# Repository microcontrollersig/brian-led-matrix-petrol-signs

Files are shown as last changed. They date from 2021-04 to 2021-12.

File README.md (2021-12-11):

# Big LED Matrix from Petrol Pump Signage

#### Info

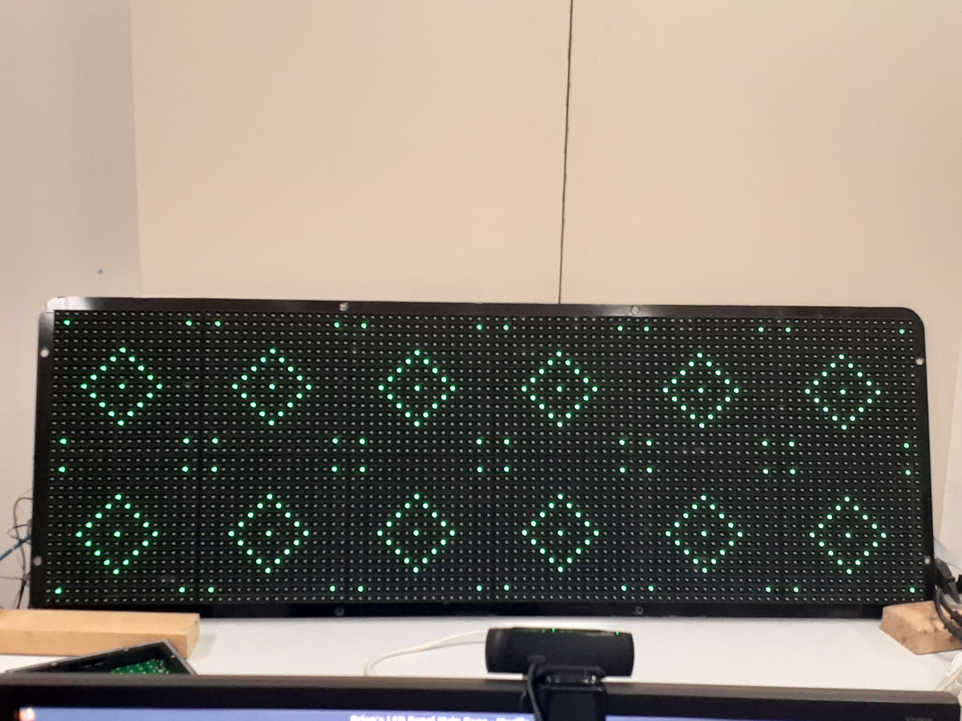
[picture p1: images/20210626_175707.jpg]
LED Panel Demo


Not the usual HUB08/HUB12/HUB40/HUB75 style setup. Inner workings [here](https://github.com/microcontrollersig/brian-led-matrix-petrol-signs/blob/main/REVERSEENGINEER.md)

They usually come in 6 panels wide, 2 panels height (effectively becomes a 96x32 single-color LED matrix)

# PCB Controller for LED matrix

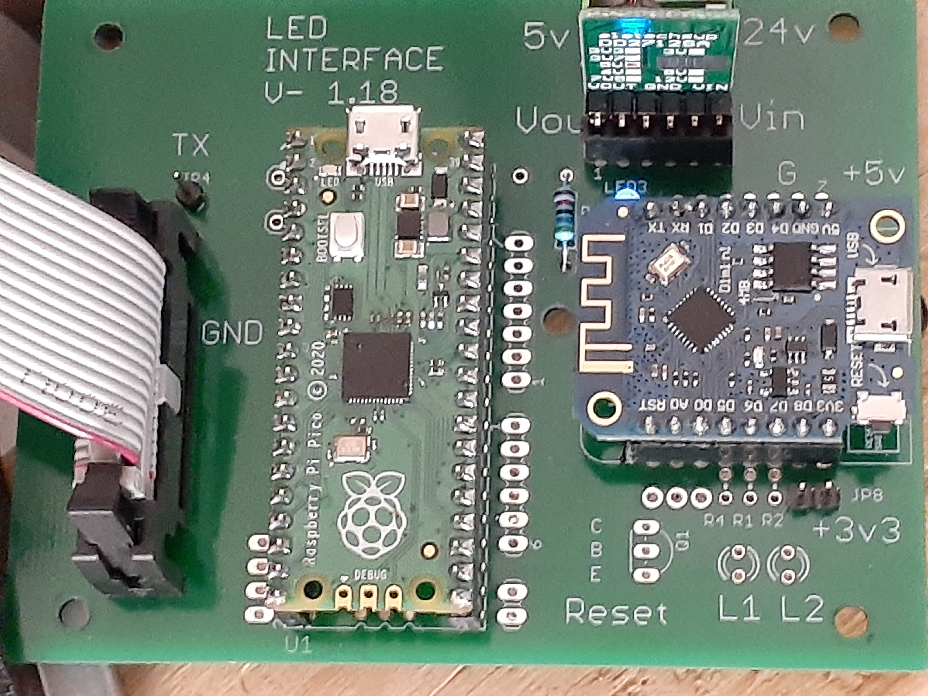
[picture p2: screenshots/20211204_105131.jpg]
LED matrix controller


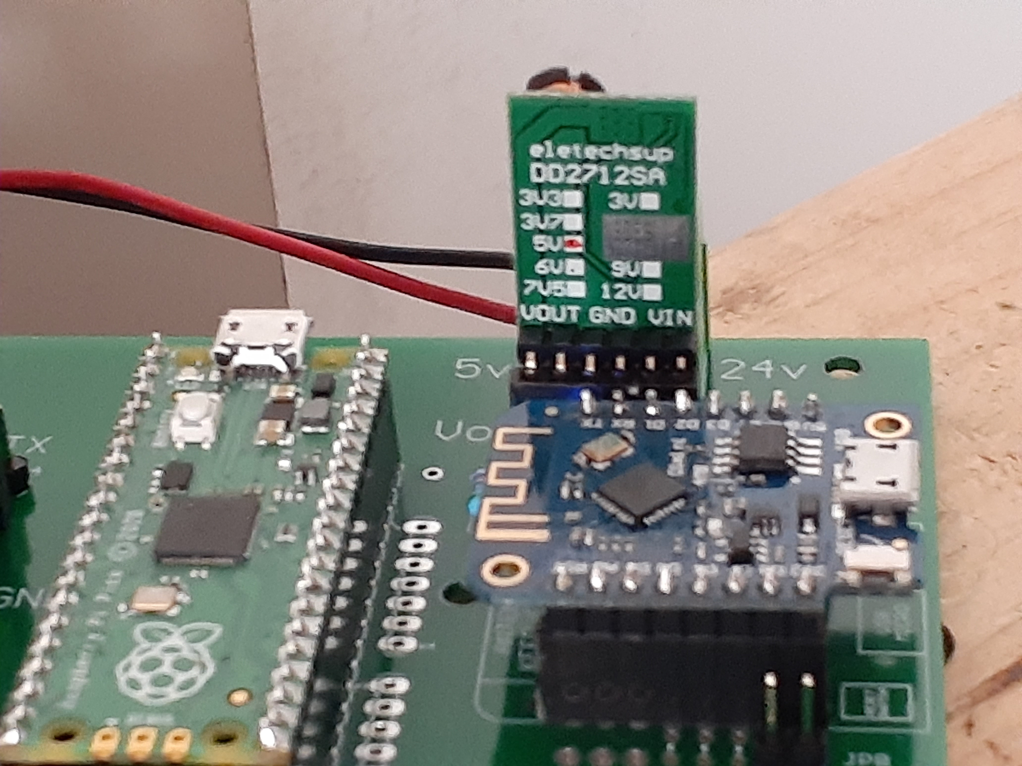
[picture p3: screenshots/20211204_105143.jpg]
PCB controller


#### Bill of Materials

| Qty | | Code | Where to Buy | Required |
| --- | --- | --- | --- | --- |
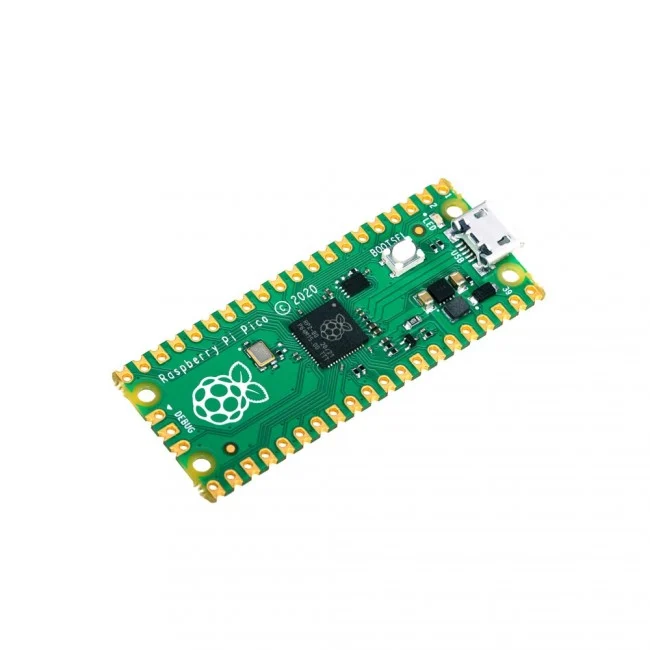
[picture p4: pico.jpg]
Pico
| 1 |  | [Raspberry Pico](https://www.raspberrypi.org/documentation/rp2040/getting-started/) | [Pi Australia](https://raspberry.piaustralia.com.au/products/raspberry-pi-pico?variant=32587824070705)<br/>[Altronics](https://www.altronics.com.au/p/z6421-raspberry-pi-pico-microcontroller-board/)<br/>[Element 14](https://au.element14.com/raspberry-pi/raspberry-pi-pico/raspberry-pi-32bit-arm-cortex/dp/3643332)<br/>[Core Electronics](https://core-electronics.com.au/raspberry-pi-pico.html) | Y |
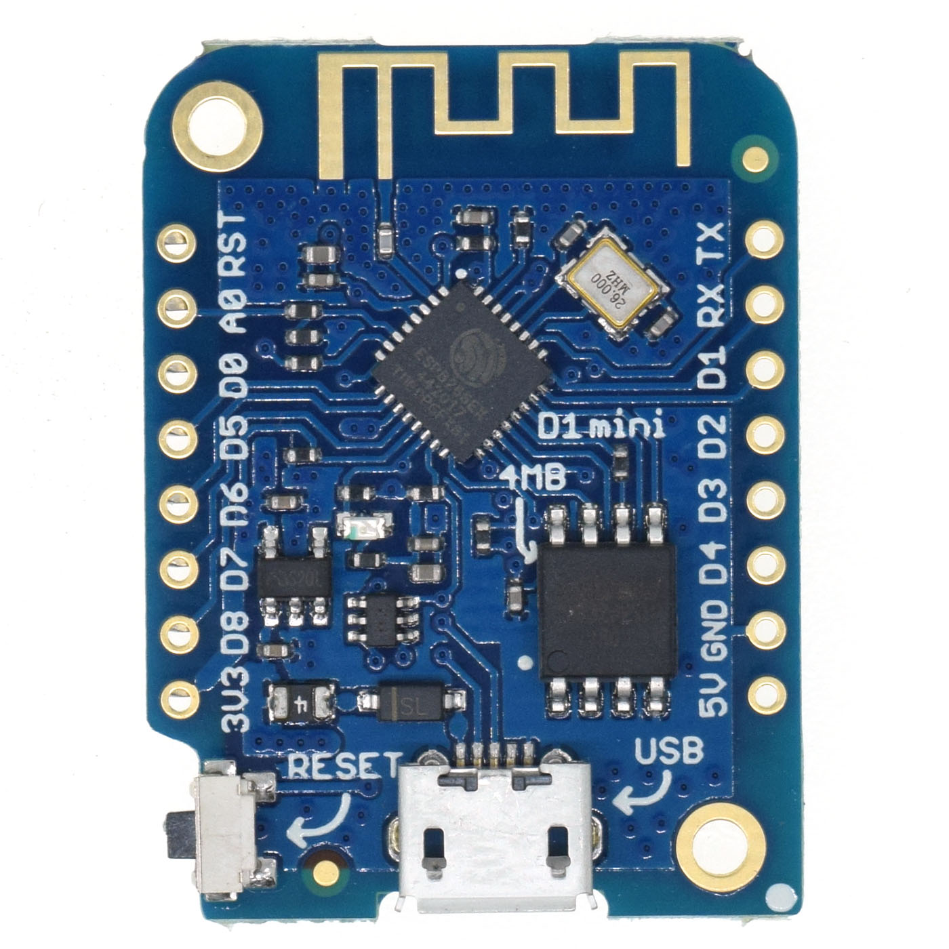
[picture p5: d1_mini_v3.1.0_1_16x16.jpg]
D1 mini
| 1 |  | [ESP8266 Wemos D1 mini](https://www.wemos.cc/en/latest/d1/d1_mini.html) | [Aliexpress - color: d1 mini](https://www.aliexpress.com/item/32651747570.html) | Y |
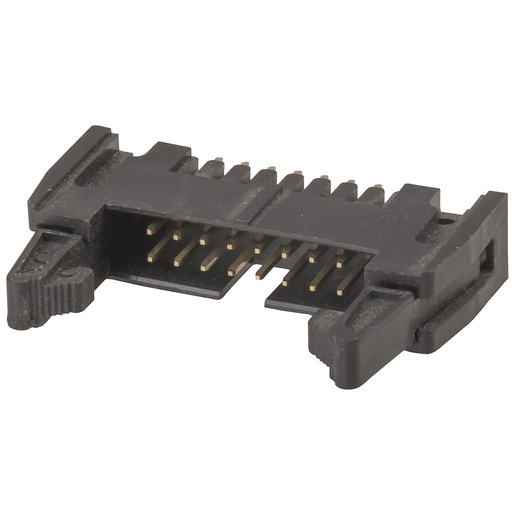
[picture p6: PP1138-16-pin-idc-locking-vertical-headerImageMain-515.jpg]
16 Pin IDC
| 1 |  | [16 Pin IDC Locking Vertical Header](https://www.jaycar.com.au/16-pin-idc-locking-vertical-header/p/PP1138) | 16-pin ribbon header | Y |
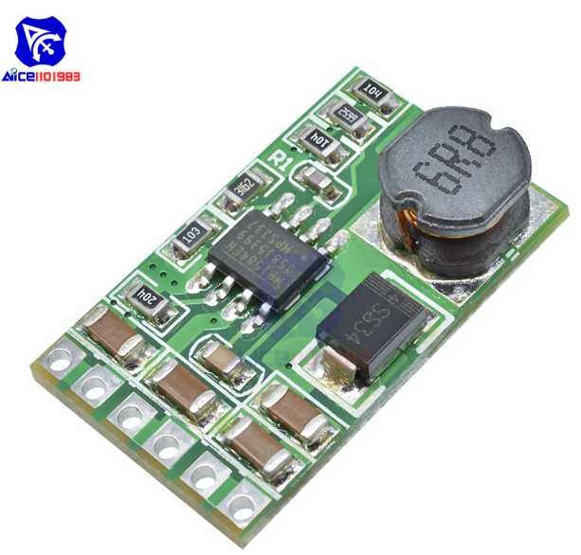
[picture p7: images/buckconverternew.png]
buck converter
| 1 |  | [3.5A buck converter - color: 5V](https://www.aliexpress.com/item/33036075561.html) | Buck converter | Y |
| 1 | Terminal block | [Terminal block](https://www.altronics.com.au/p/p2041a-dinkle-3-way-5.08mm-pcb-mount-terminal-block/) | External power source | Y |
| 1 | Disk Drive Power Connector Socket | [Disk Drive Power Connector Socket](https://www.jaycar.com.au/disk-drive-power-connector-socket/p/PS0742) | Power connector from LEDs to terminal block | N |
| 1 | Female header | [Female header](https://www.jaycar.com.au/40-pin-female-header-strip/p/HM3230) | Female header for Pico | Y |
| 1 | Right-angle connector | [Right-angle connector ](https://www.rockby.com.au/CatresultsSql_12.cfm?select=33&subcode=142&stock_no=27464) | Need for connecting buck converter | Y |
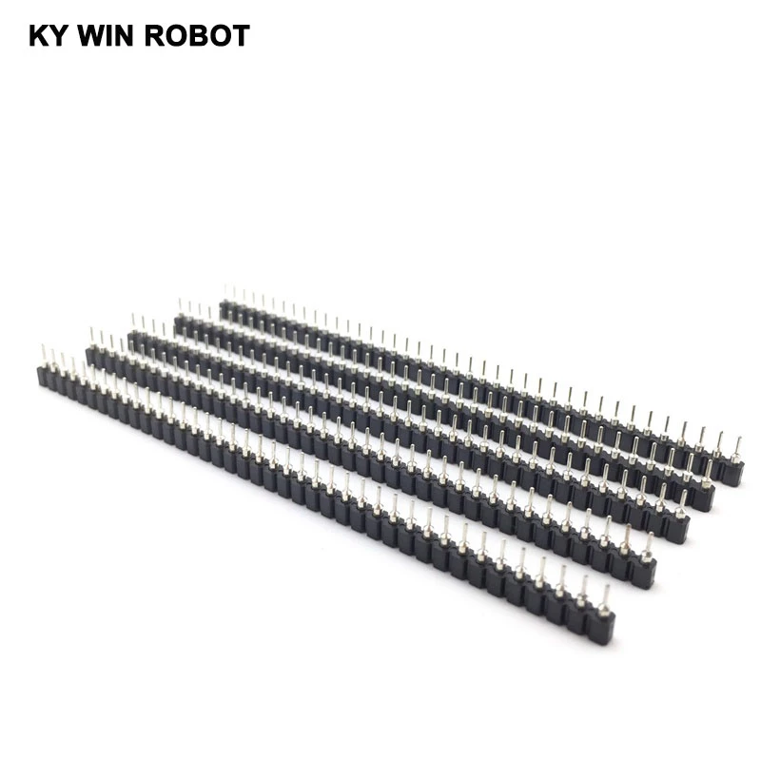
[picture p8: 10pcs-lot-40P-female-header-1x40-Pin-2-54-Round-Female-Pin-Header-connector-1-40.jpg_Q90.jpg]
Female Header
| 1 |  | [Round Female Pin Header connector - snapable](https://www.aliexpress.com/item/32848204130.html) | Aliexpress | N |
| 1 | 2N2222A | [2N2222A NPN transistor](https://www.jaycar.com.au/2n2222a-npn-transistor/p/ZT2298) | Pico software-controlled reset switch | N |

#### EAGLE Schematic for PCB Board

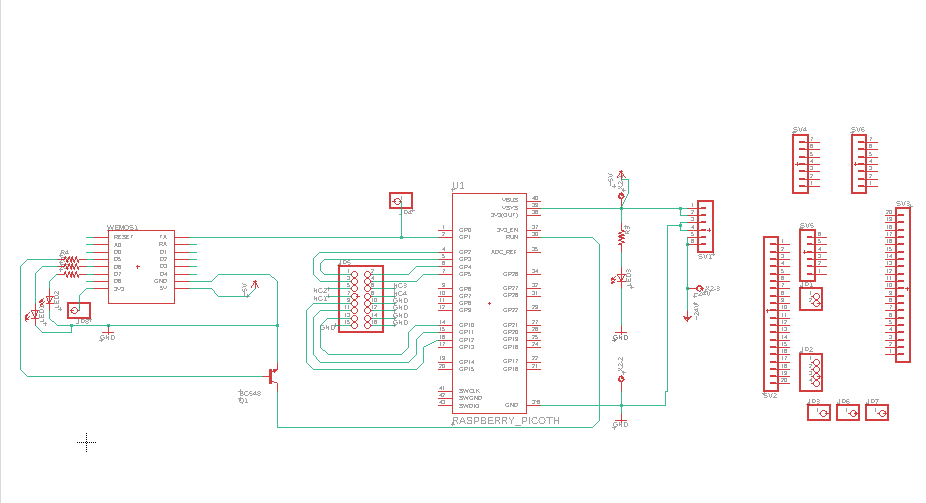
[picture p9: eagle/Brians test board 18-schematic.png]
schematic


#### EAGLE Board file for PCB Board

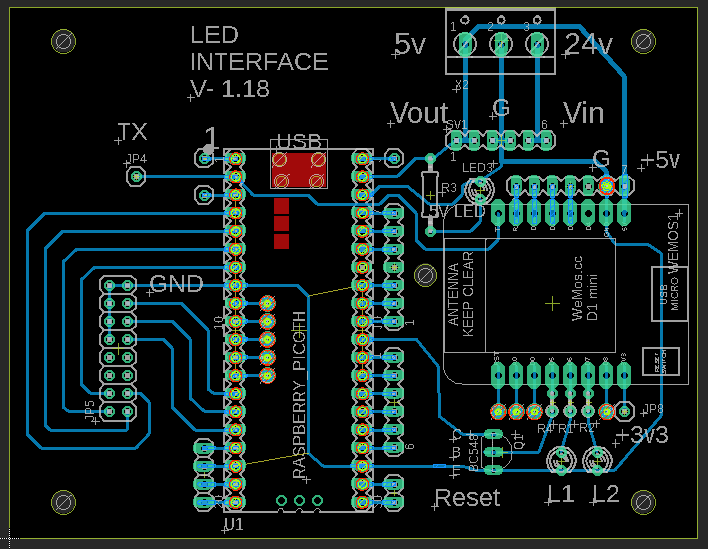
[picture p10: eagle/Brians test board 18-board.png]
board


### PCB Top Layer

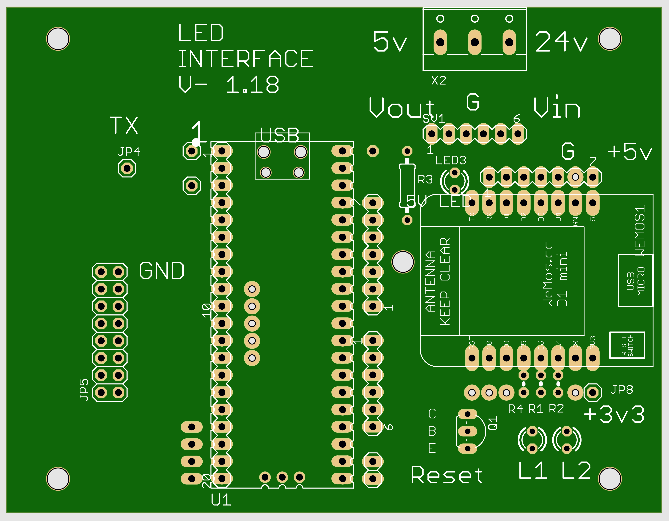
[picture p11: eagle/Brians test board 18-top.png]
PCB Top Layer


#### PCB Bottom Layer

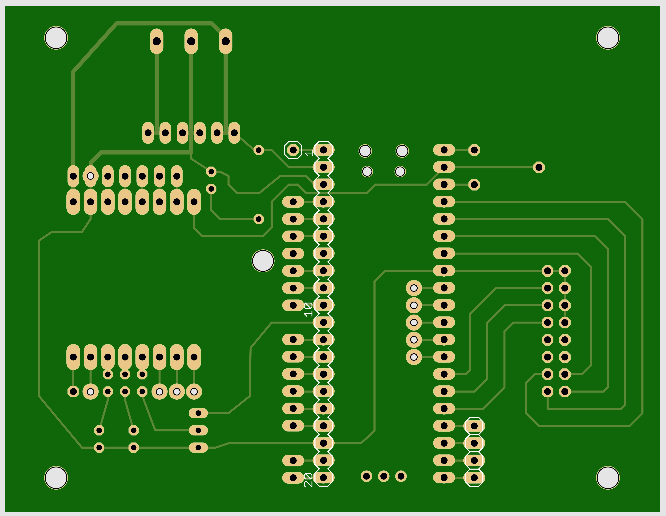
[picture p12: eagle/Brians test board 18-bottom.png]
PCB Bottom Layer


#### Raspberry Pi Pico

pinout

#### ESP8266 wemos d1 mini

pinout

# Software

Steps needed to complete software setup:

- Firmware needs to be uploaded to Pico, firmware also need to be uploaded to esp8266 D1 mini.
- wifi configuration of D1 mini.

In order to complete these steps, must first do the following steps on your computer:

- Download zip file containing firmware files and CH340 Windows driver for D1 mini from [here](https://github.com/microcontrollersig/brian-led-matrix-petrol-signs/releases/latest/download/brian-petrol-signs-easy-firmware-upload.zip) . Unzip the file to a known location on your computer.
- Download a ESP8266 flash utility. There are a number available, my preferred one is ESPHome-Flasher, which can be
  downloaded from [here](https://github.com/esphome/esphome-flasher/releases) .

## Uploading firmware to Raspberry Pico

[Click here for details](https://github.com/microcontrollersig/brian-led-matrix-petrol-signs/tree/main/code/pico).

## Uploading firmware to D1 mini and configuring wifi

[Click here for details](https://github.com/microcontrollersig/brian-led-matrix-petrol-signs/tree/main/code/d1mini)

# Roles of Microprocessors

## Pico

- update LED matrix
- receive commands from the D1 mini via serial(RX).

## ESP8266 D1mini

- Present user with web interface for controlling LED matrix.
- Send commands for the Pico to execute on the LED matrix via Serial(TX).

# References

- [How LED matrix was reverse engineered](https://github.com/microcontrollersig/brian-led-matrix-petrol-signs/blob/main/REVERSEENGINEER.md)

- [Eagle files](https://github.com/microcontrollersig/brian-led-matrix-petrol-signs/tree/main/eagle)

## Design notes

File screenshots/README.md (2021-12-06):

     # Screenshots
 
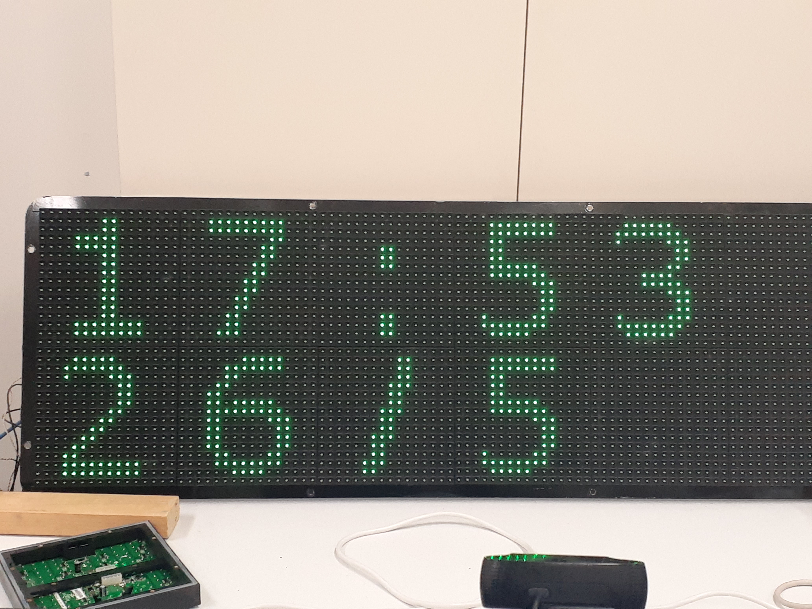
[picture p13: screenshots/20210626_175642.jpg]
   

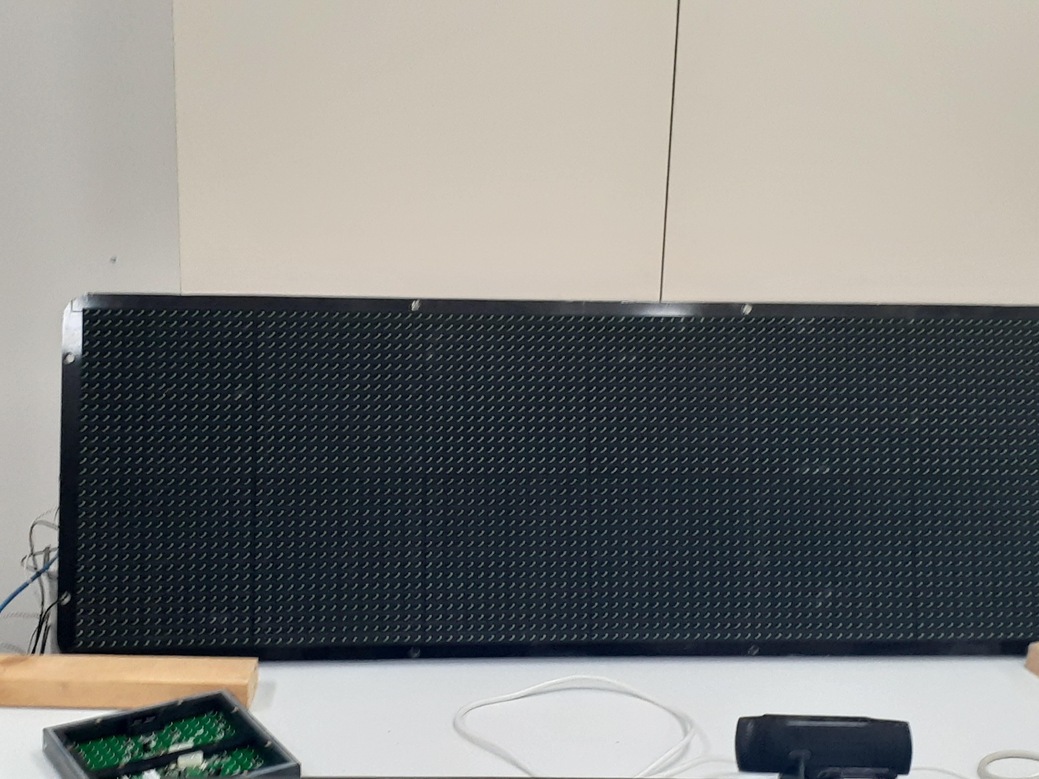
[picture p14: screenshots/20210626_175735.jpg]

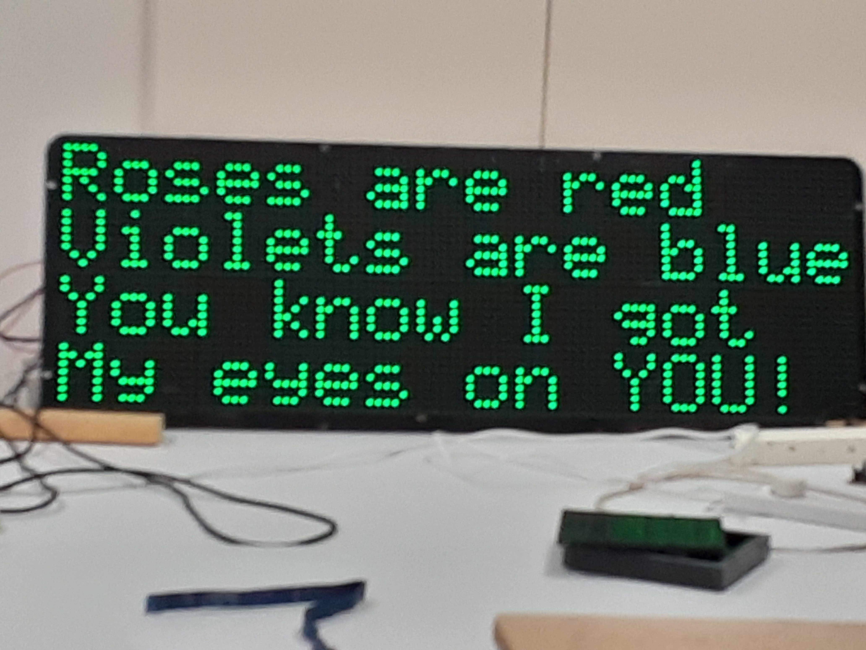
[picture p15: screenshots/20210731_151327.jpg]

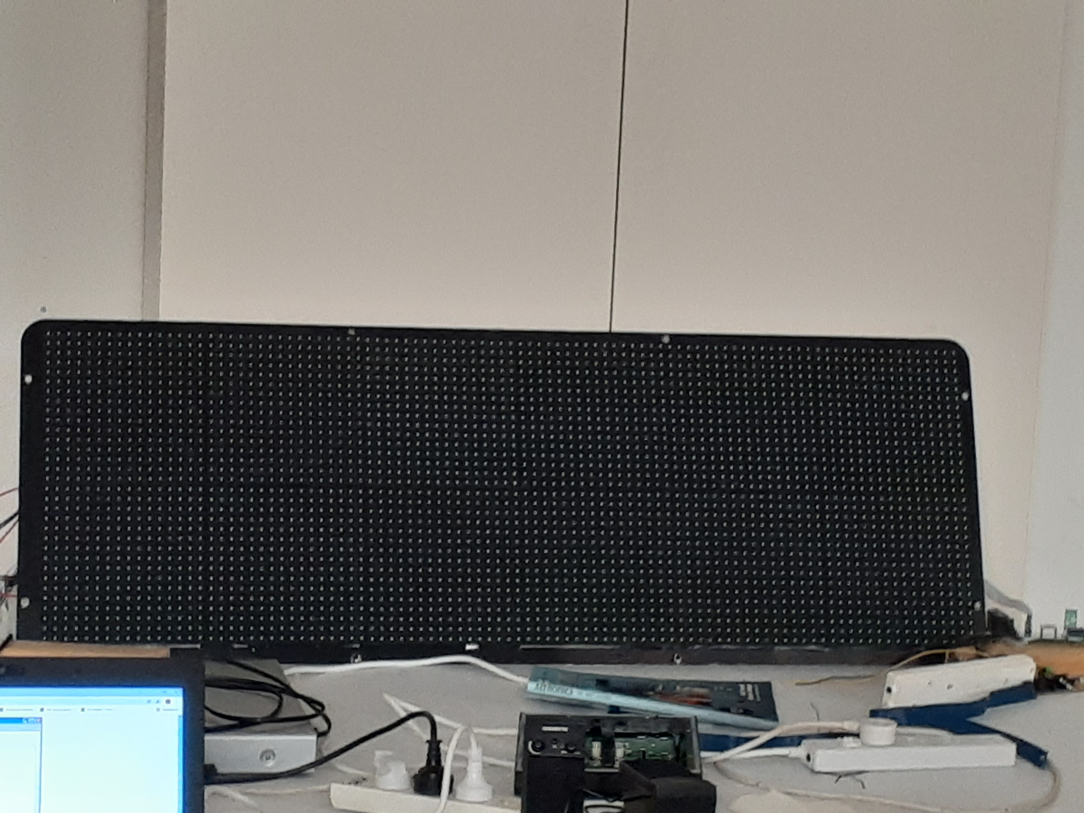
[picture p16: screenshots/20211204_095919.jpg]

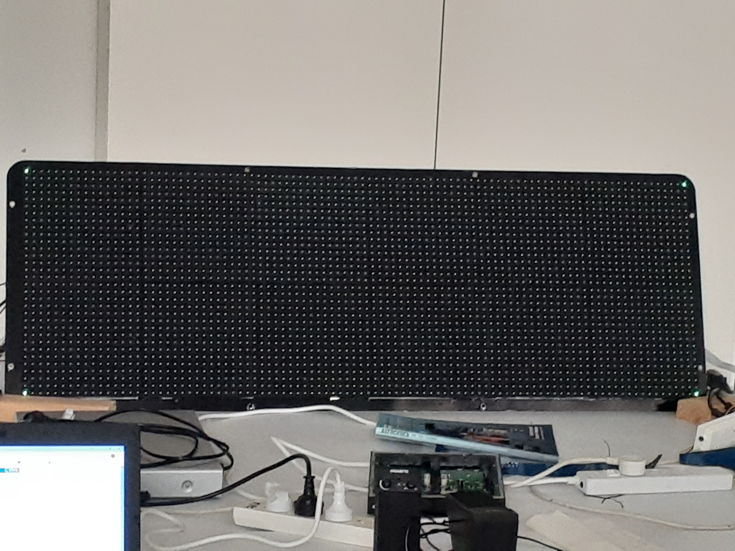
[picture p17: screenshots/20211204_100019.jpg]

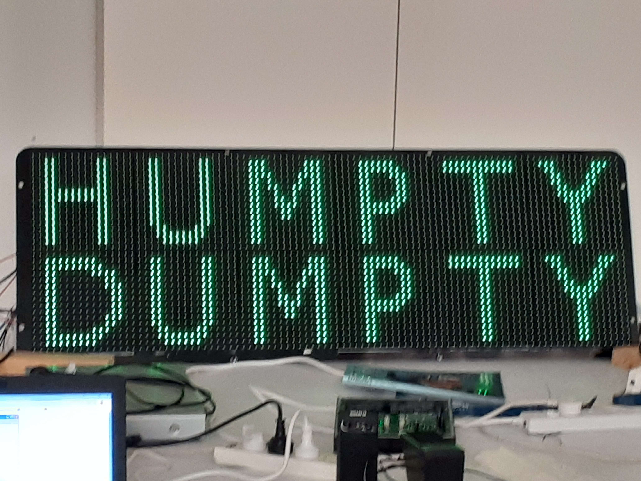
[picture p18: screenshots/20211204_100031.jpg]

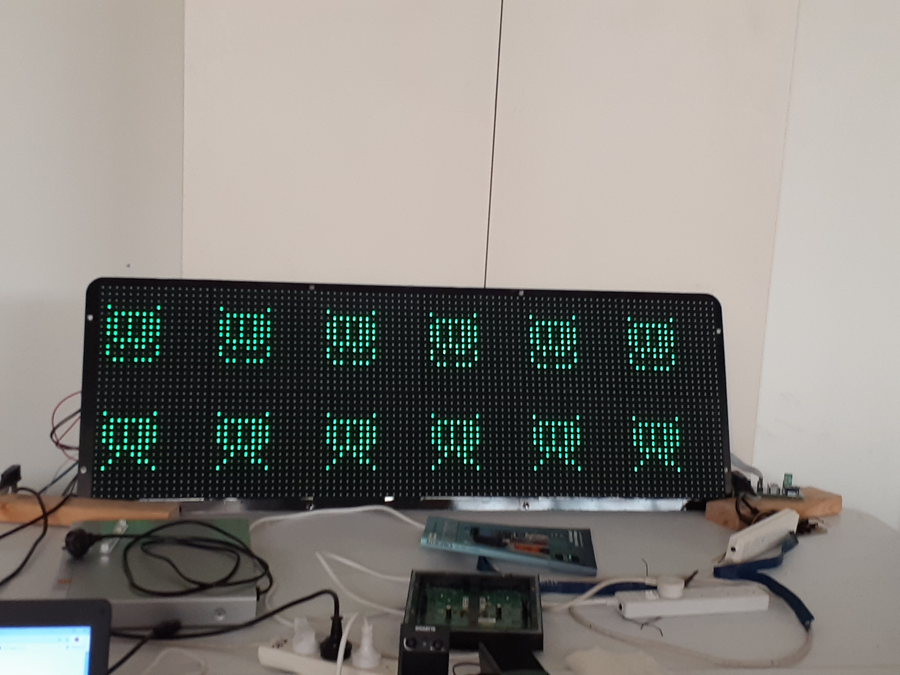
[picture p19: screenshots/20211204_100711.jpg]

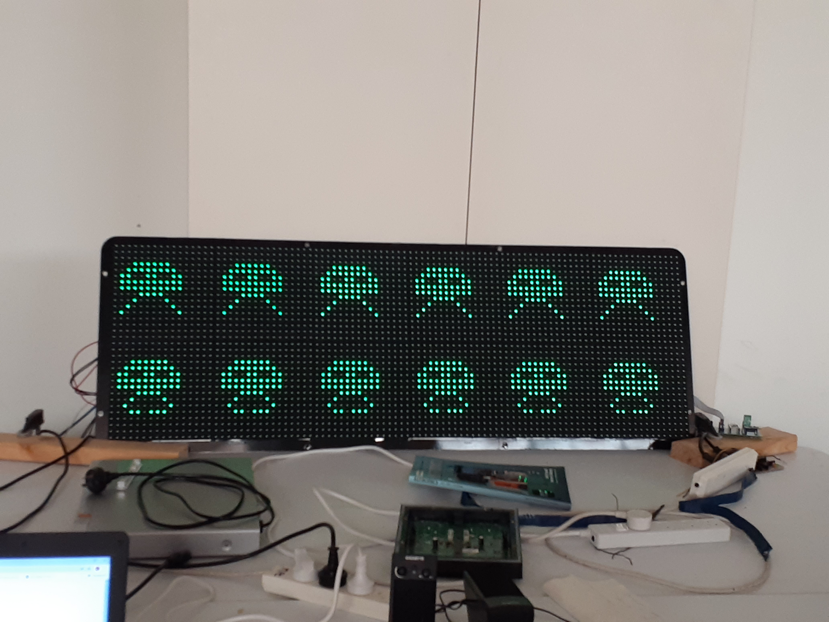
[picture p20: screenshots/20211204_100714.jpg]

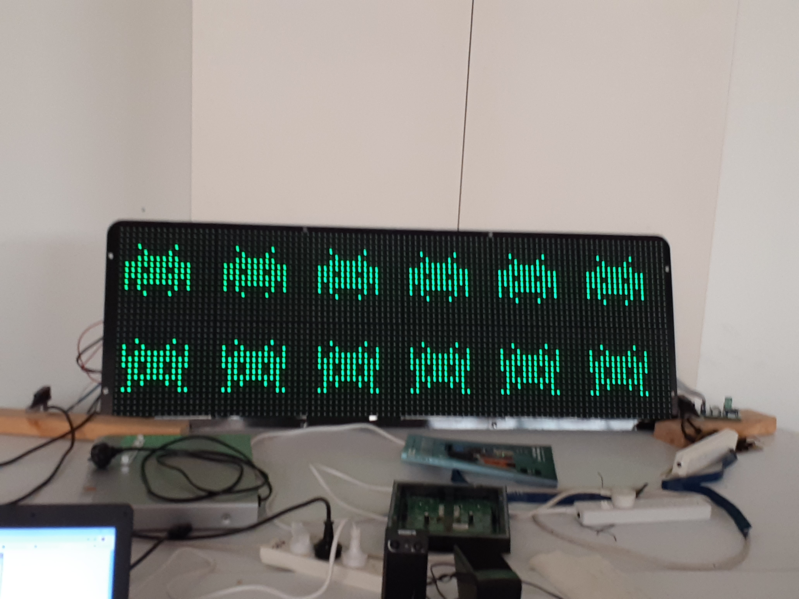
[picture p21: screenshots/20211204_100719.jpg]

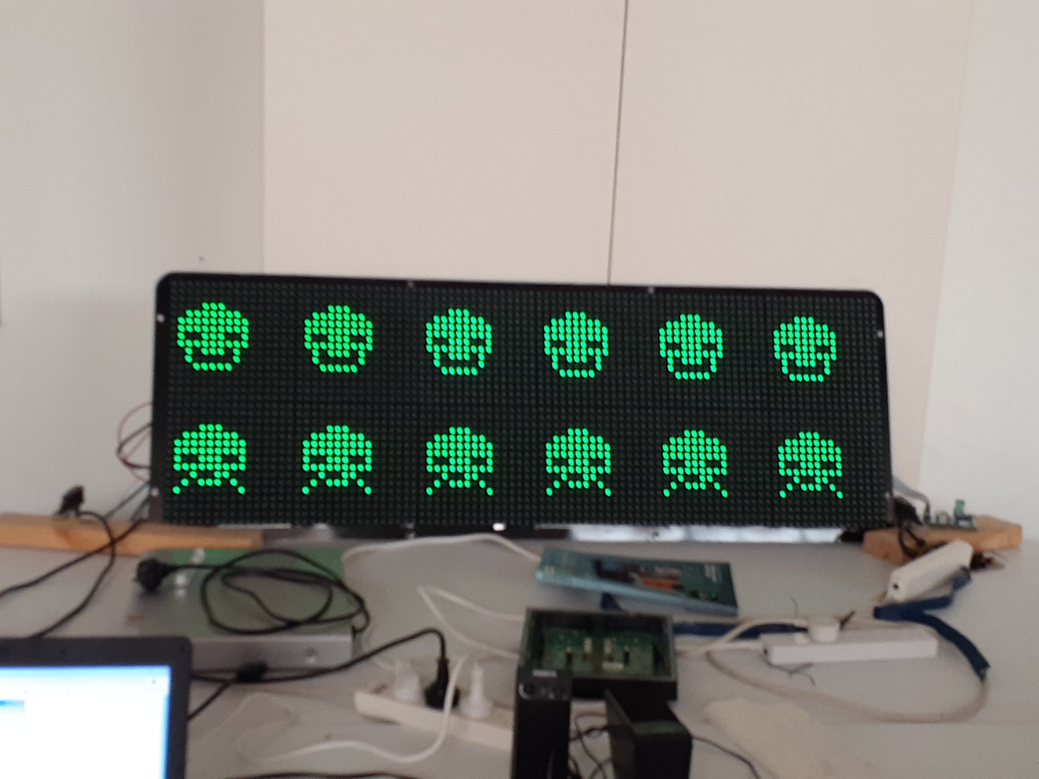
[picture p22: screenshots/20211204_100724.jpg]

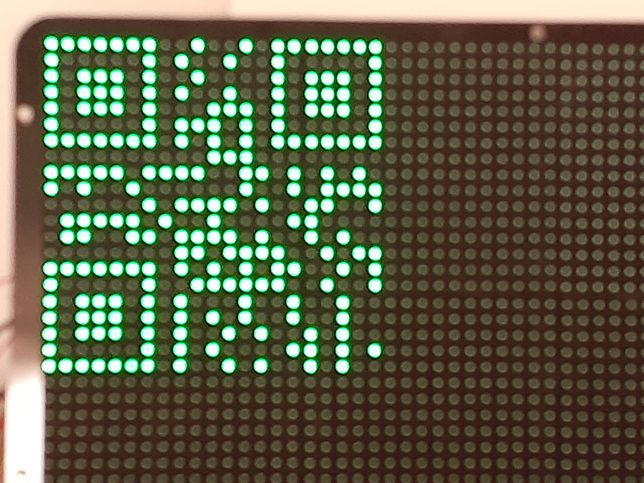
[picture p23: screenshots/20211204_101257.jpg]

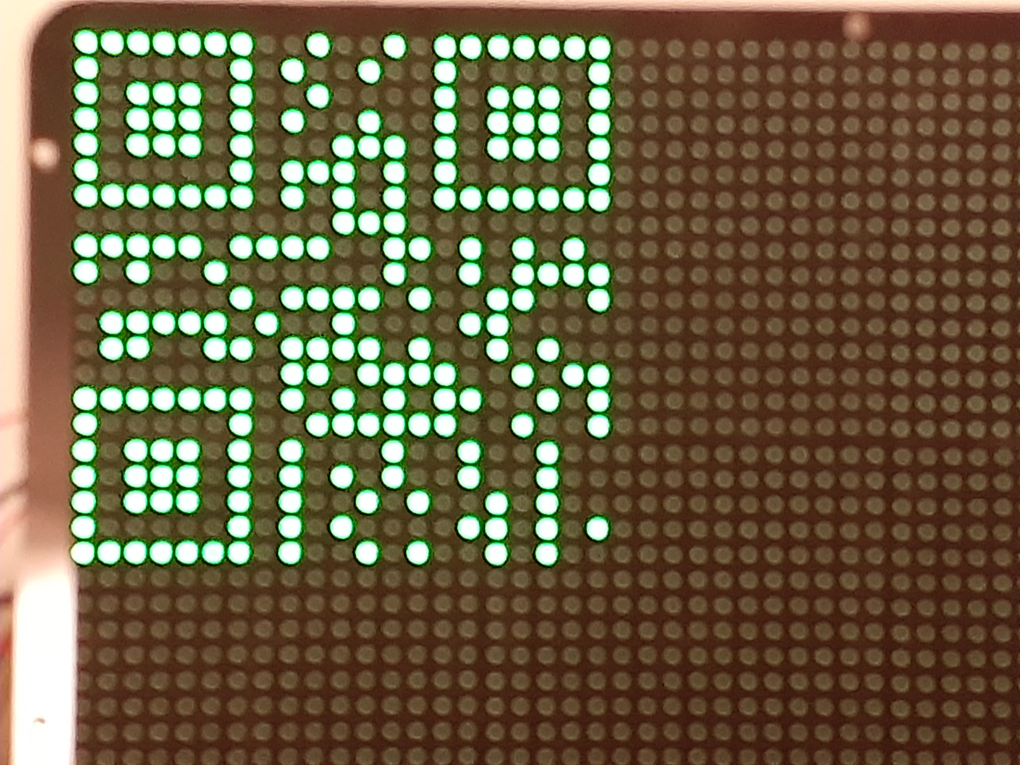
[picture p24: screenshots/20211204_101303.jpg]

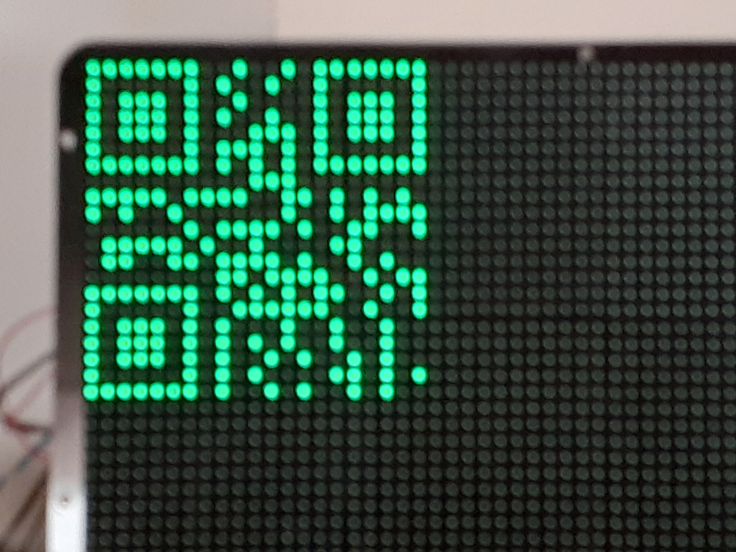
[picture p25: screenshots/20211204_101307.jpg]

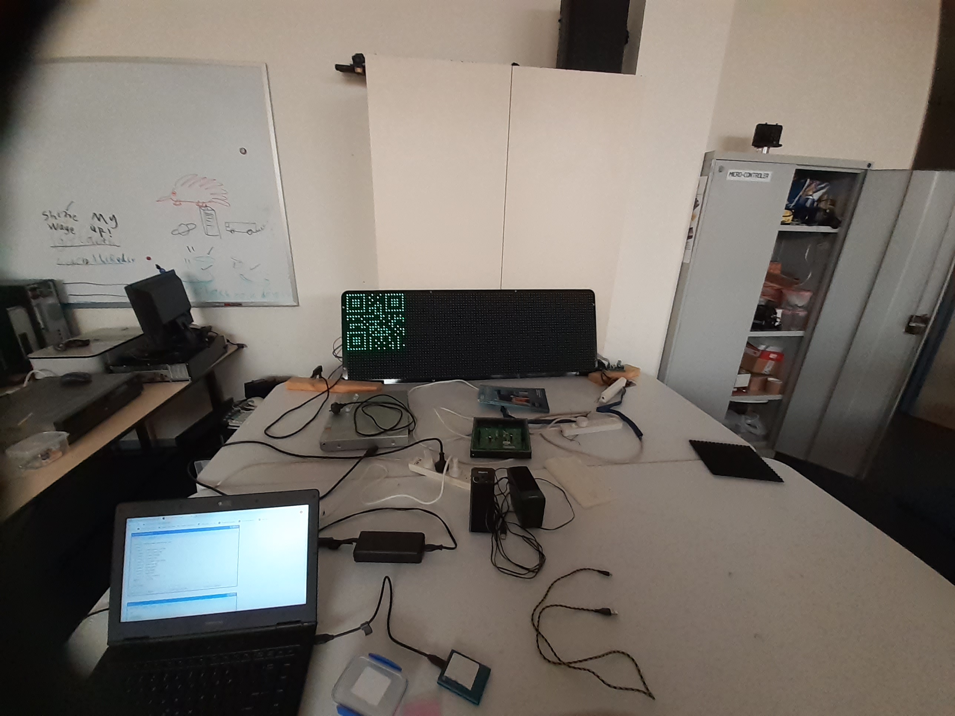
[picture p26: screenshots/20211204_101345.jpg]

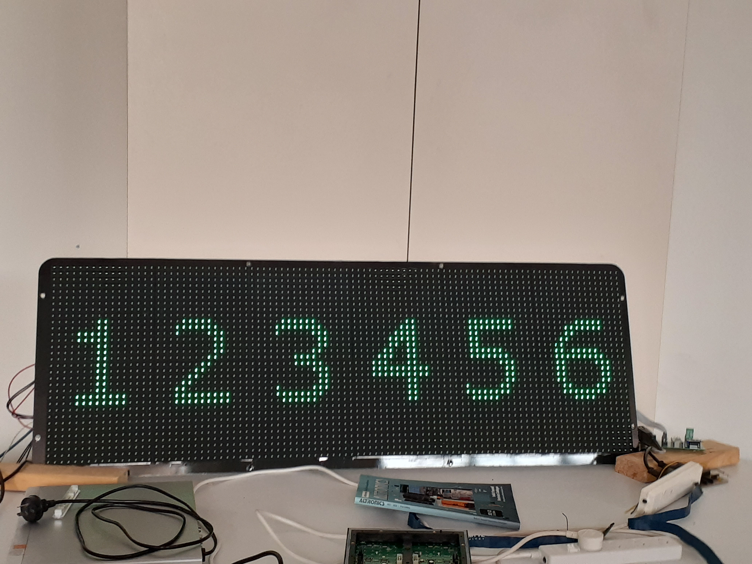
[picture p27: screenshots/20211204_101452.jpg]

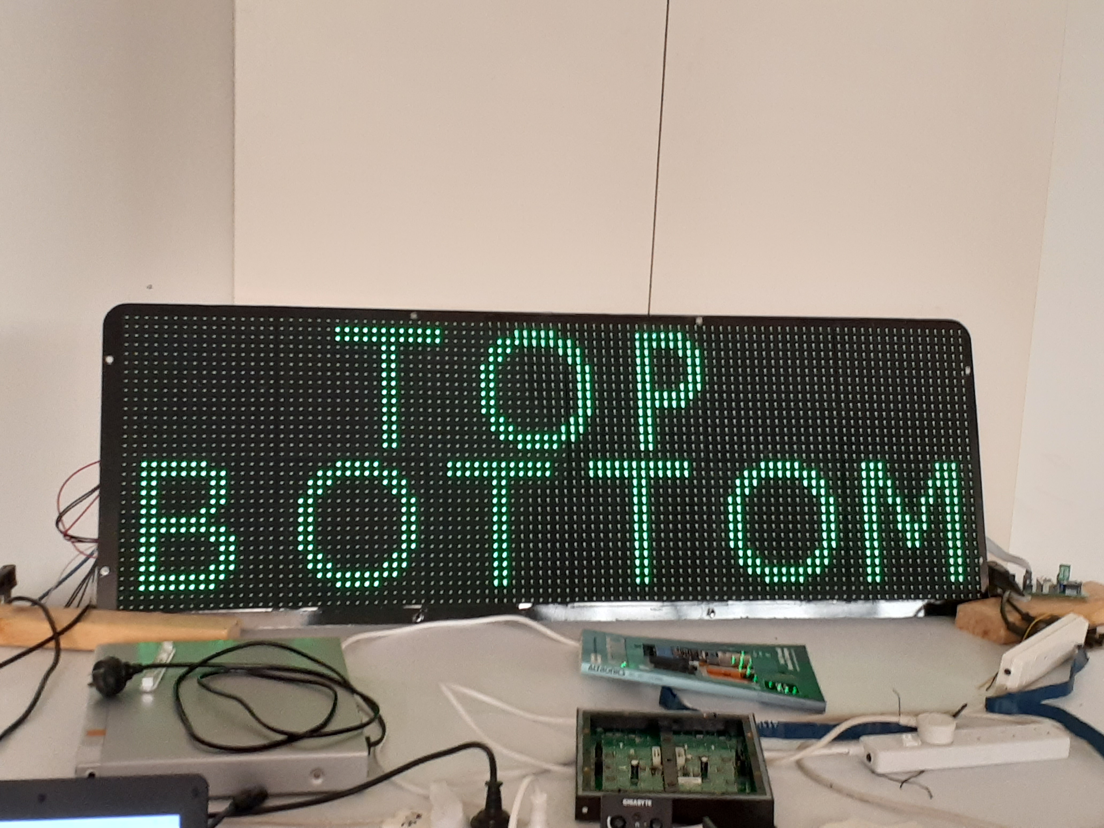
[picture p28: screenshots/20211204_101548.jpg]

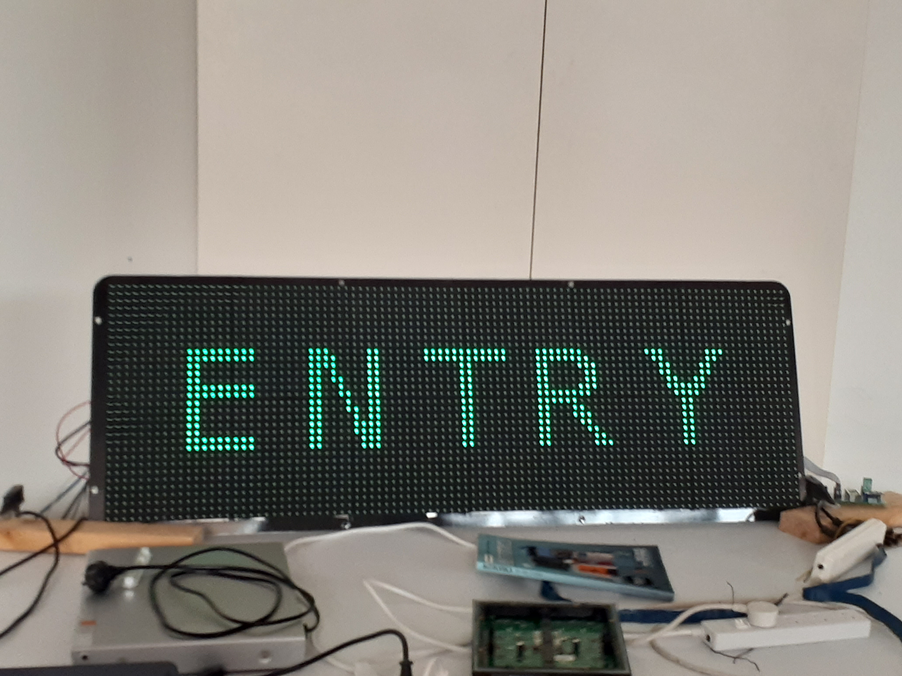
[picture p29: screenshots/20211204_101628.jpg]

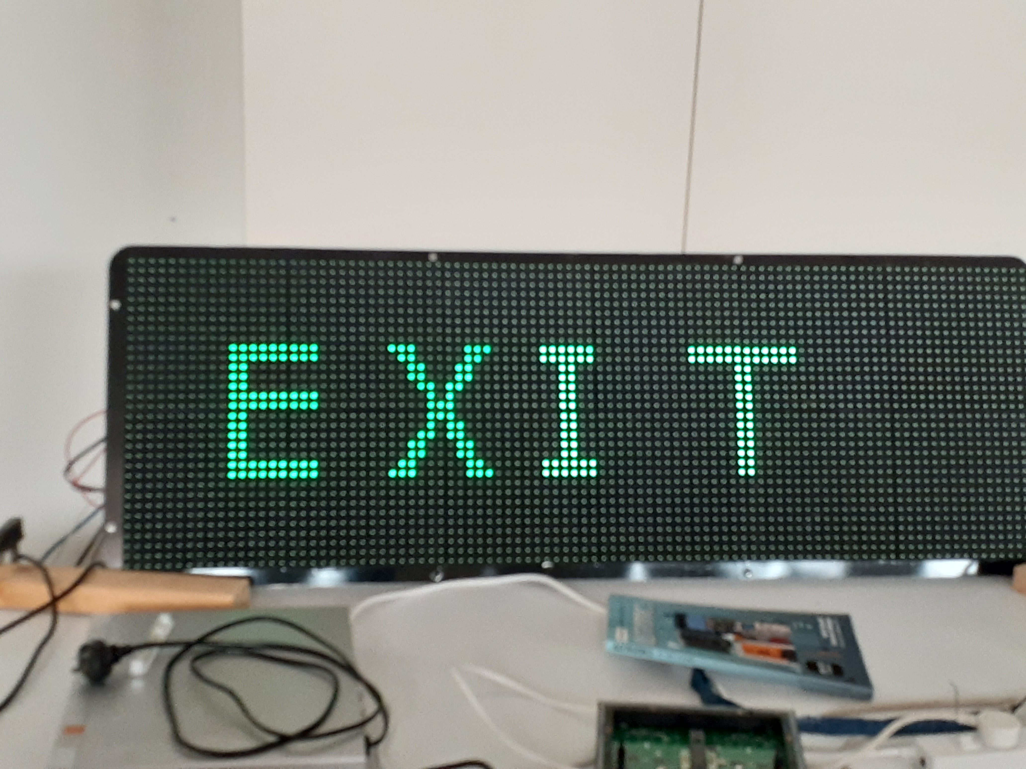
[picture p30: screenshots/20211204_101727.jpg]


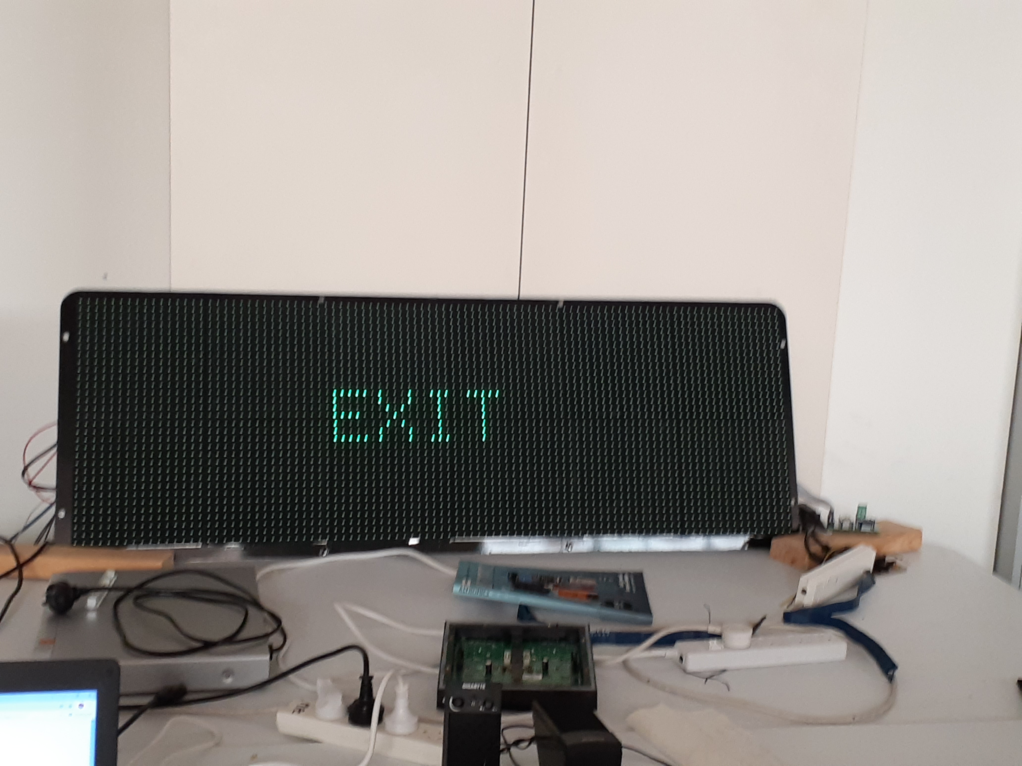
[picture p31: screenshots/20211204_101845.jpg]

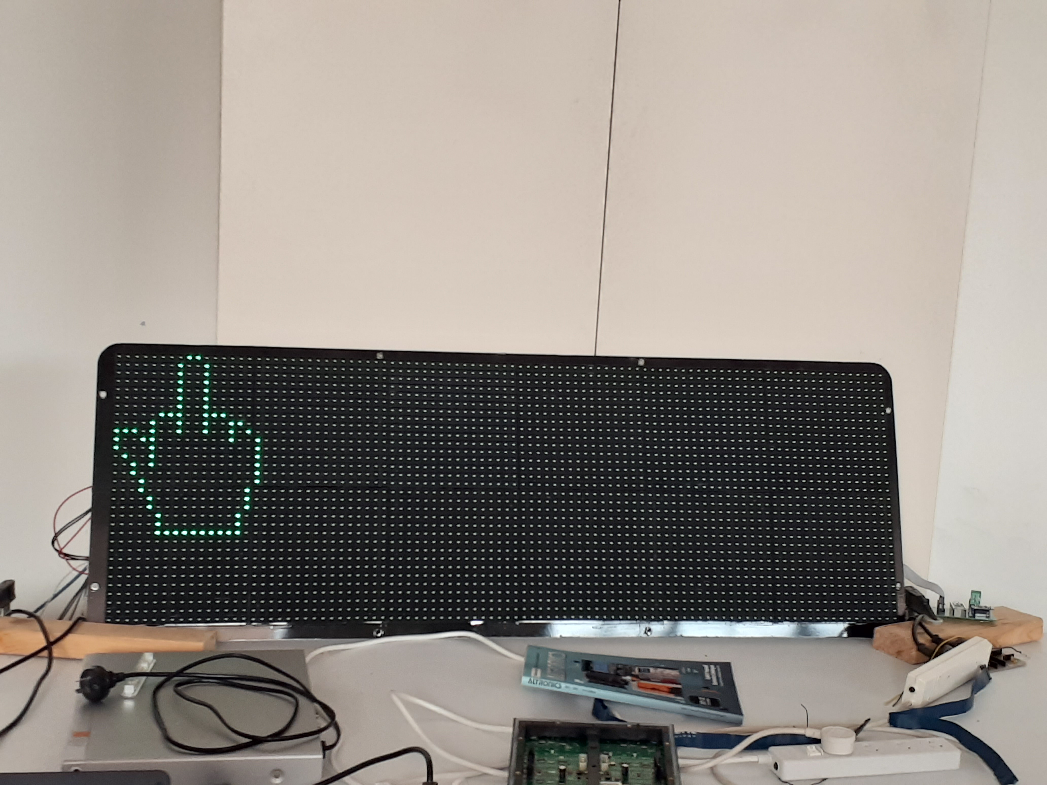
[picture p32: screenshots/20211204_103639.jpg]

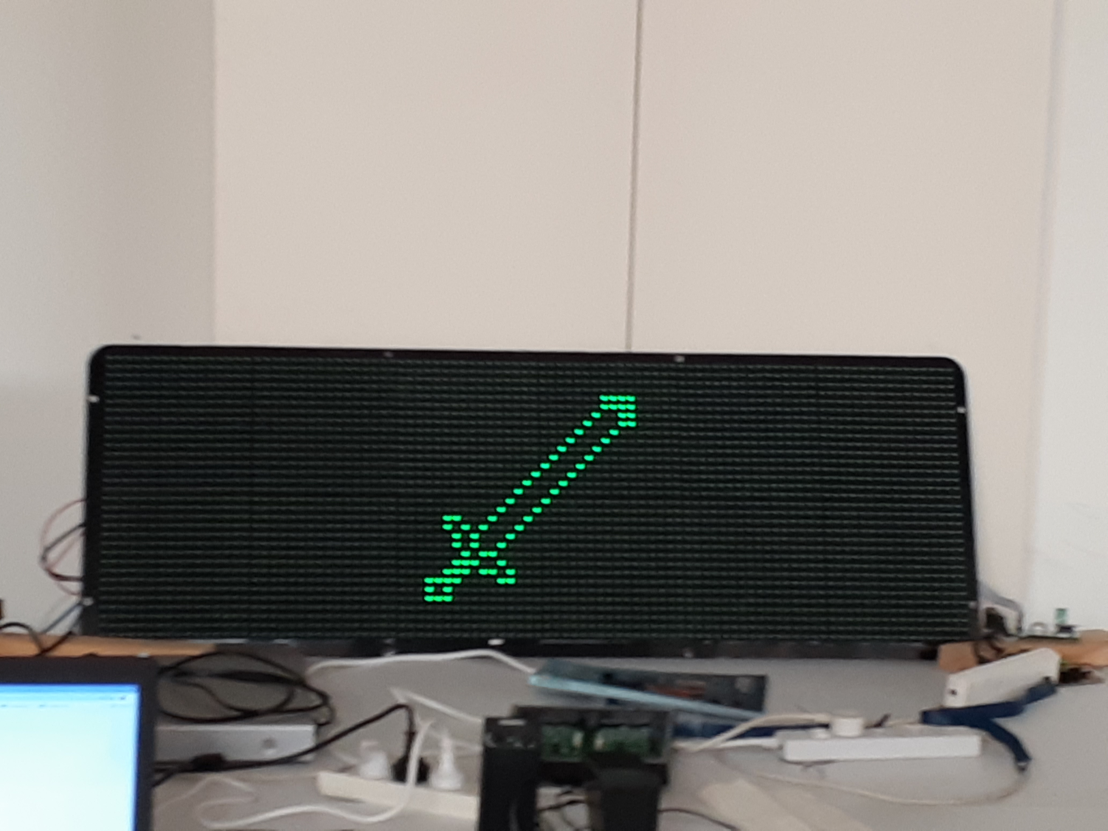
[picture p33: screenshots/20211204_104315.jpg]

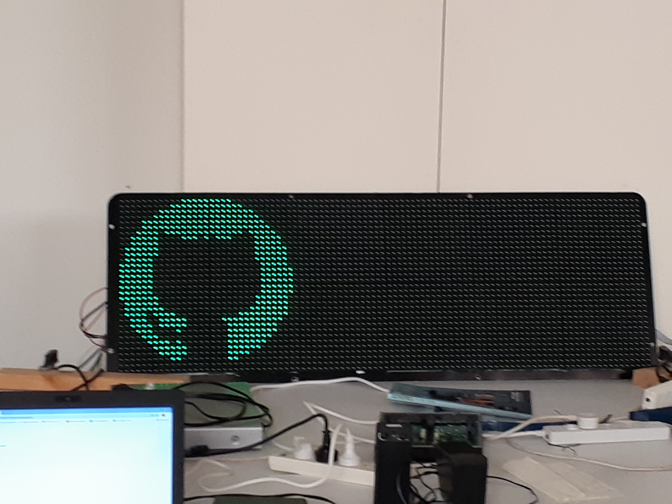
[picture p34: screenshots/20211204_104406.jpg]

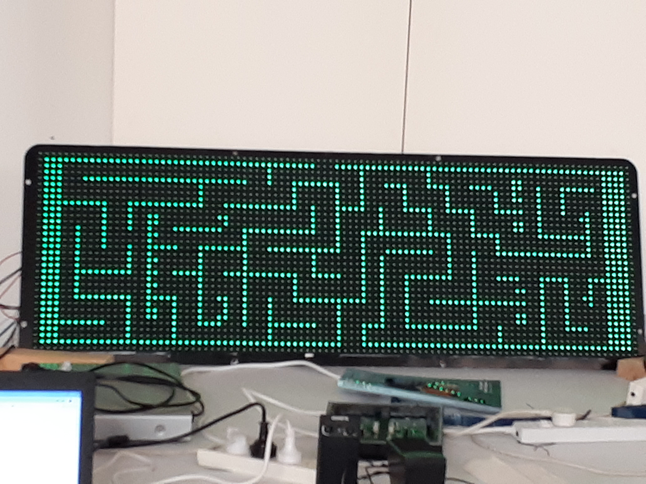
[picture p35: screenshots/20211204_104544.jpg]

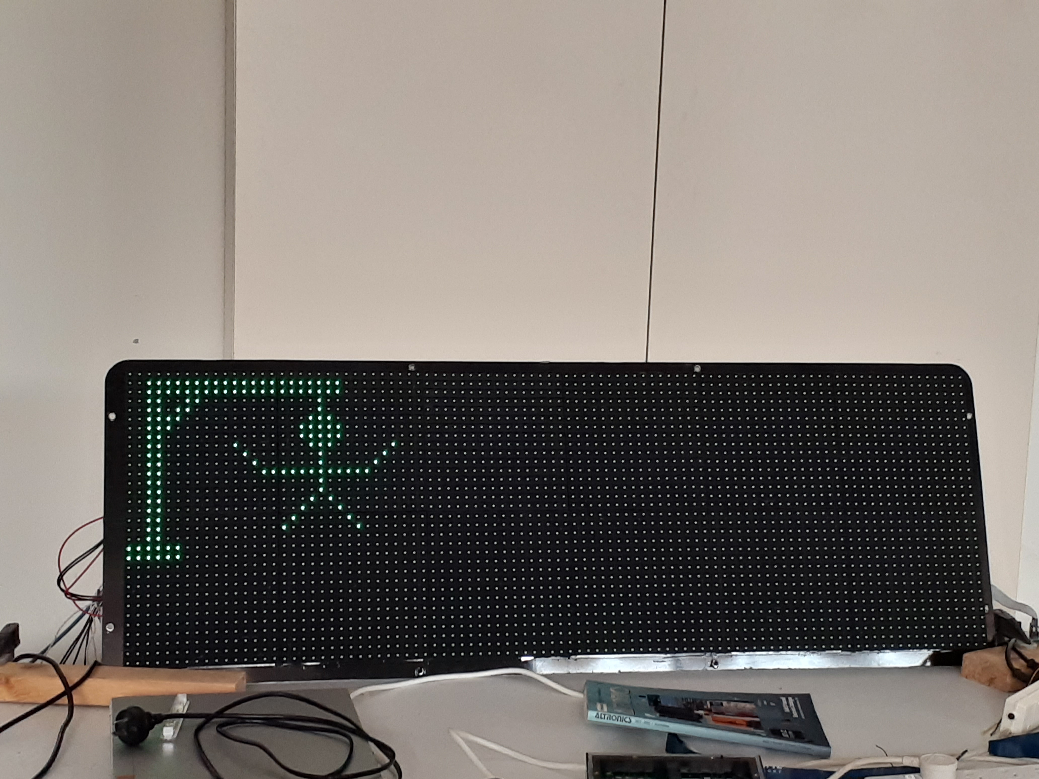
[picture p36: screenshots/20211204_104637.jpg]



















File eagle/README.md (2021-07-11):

# Eagle Files

Latest version is v1.18

# JLCPCB
[JLCPCB gerber viewer at checkout](https://cart.jlcpcb.com/quote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)

[gerber viewer](https://www.pcbway.com/project/OnlineGerberViewer.html)

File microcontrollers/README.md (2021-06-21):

# Raspberry Pico

Pico powertrain

Pico powertrain

# Esp8266 Wemos D1 mini

D1 mini powertrain

#### D1 mini troubleshooting

[Protection diode failing](https://www.reddit.com/r/esp8266/comments/7he3ad/found_a_fix_for_my_dead_wemos_d1_mini_today/)

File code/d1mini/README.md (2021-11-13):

# Uploading software to D1 mini

### Prerequisite for Windows PC
1. Download Windows driver for D1 mini from [here](https://www.wemos.cc/en/latest/ch340_driver.html) 
2. Unzip CH341SER_WIN_3.5.ZIP .
3. Open the CH341SER_WIN_3.5 folder and run SETUP.EXE

Alternatively, a copy of the windows driver is also included in the zip file you download in the next step.

### Use ESPHome Flasher (easiest method)

1. Need to complete steps from [here](https://github.com/microcontrollersig/brian-led-matrix-petrol-signs/blob/main/README.md#Software)
2. Find **d1mini.bin** inside the unzipped folder you downloaded in previous step.
4. Open ESPHome-Flasher
    - Select Serial port
    - On the Firmware line, click **Browse** and open the **d1mini.bin** file
    - Press **Flash ESP** button
    - Wait for firmare to upload, don't close the program yet, go down to the section **Need to configure D1 mini**     

### Use Arduino IDE (hard method)

See [here](https://github.com/microcontrollersig/brian-led-matrix-petrol-signs/blob/main/code/d1mini/BUILDING.md)

# Need to configure D1 mini

After you click **Flash ESP** and the firmwware is uploaded, the D1 mini will restart and boot for the first time.

The first thing that happens is that it creates a Wifi network called **brianLEDPanels** with an IP address of **192.168.4.1** 

Here are the steps you need to take to complete firmware installation on D1 mini:

1. Connect to the wifi network **brianLEDPanels**
2. Open a browser and type **192.168.4.1**
3. You should see this screen:
   
   Captive Portal
   
5. Enter your Wifi network name and password under the primary wifi network section, and optionally, you can give a secondary
   /alternate wifi network
5. Click **Save & Connect**
6. If all goes well, you should see this screen:

   Captive Wifi success

7. Success. Now connect to either the Primary or Secondary wifi networks, and you should now see the IP address show up in 
   the ESPHomeFlasher logs.
8. Enter the IP address in the browser and if you get a webpage back, installation is complete.

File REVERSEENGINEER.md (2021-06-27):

# Reverse Engineering Brian's Petrol Pump LED Matrix

Here is the backside of one 16x16 panel up close and personal (Thanks to Brian D. for awesome shot).

LED Panel

Important note: The 74HC245 operates at **3.3V**, and therefore any inputs connected to the 16-pin input connector has to operate at 3.3V.

## Takeaways from Image

1. 16 pin input connector on left, direction of data flow indicated by arrow on PCB silkscreen.
2. The major components are:

   - MBI5039 constant current sink driver (reference [here](https://github.com/microcontrollersig/brian-led-matrix-petrol-signs/blob/main/MBI5039%20Datasheet.pdf) )
   - 74HC245 octal bi-directional buffer (reference [here](https://github.com/microcontrollersig/brian-led-matrix-petrol-signs/blob/main/74HC_HCT245.pdf) )
   - possibly a regulator like LM2576 (reference [here](https://github.com/microcontrollersig/brian-led-matrix-petrol-signs/blob/main/lm2576.pdf) )

## Pinouts

**74HC245**

74HC245 pinout

**MBI5039**

MBI5039 pinout

The pin marked R-EXT is connected to an external resistor, an easy way to identify other pins such as GND and VCC.

MBI5039 timing diagram

## Schematic (browseable) - represents left half of 16x16 panel (accuracy needs to be verfied) 

LED Schematic

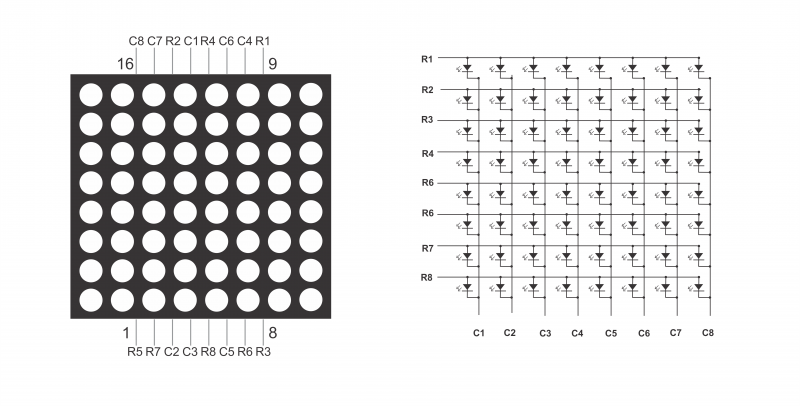
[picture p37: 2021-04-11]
8X8-Matrix-Pinout-800x406.png

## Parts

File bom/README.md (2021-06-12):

# BOM

[female header 1x40 Pin 2.54 Round Female Pin Header connector -snapable](https://www.aliexpress.com/item/32848204130.html)

[16 Pin IDC Locking Vertical Header](https://www.jaycar.com.au/16-pin-idc-locking-vertical-header/p/PP1138)

[ESP8266 D1 mini](https://www.aliexpress.com/item/32651747570.html)

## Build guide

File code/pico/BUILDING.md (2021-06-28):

# Building the UF2 file

Use the latest Arduino IDE (1.8.15 at the time of writing).

1. Install the Arduino Mbed board for RP2040 
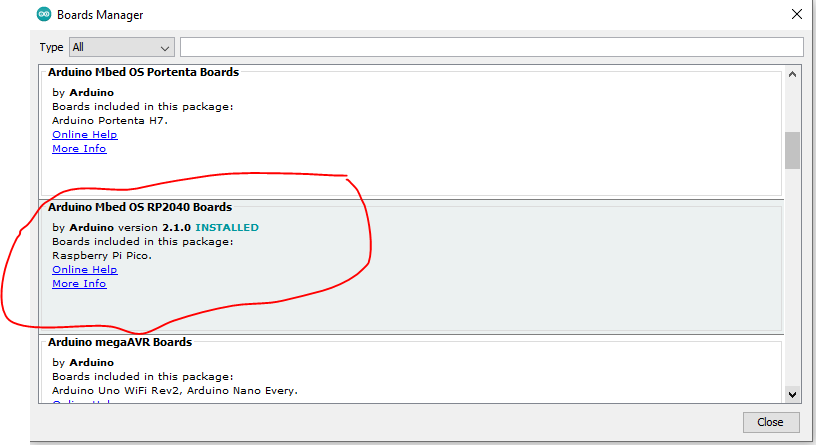
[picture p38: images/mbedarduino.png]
Mbed Arduino
   
2. In Arduino preferences, enable **Show verbose output during** for both compilation and upload.
3. Build. The last line will indicate the location of the **elf** binary file. You will need access to this file.
4. Install elf2uf2 tool from the Pico SDK.

   On Windows, install msys2, then:
   ```shell
   pacman -Syuu
   pacman -S base-devel gcc make cmake git
   git clone  https://github.com/raspberrypi/pico-sdk
   cd pico-sdk/tools/elf2uf2
   mkdir build
   cd build
   cmake ..
   make
   ./elf2uf2 -v <name_of_binary.elf> <name_of_binary.uf2>
   ```
5. You can upload to Pico as normal in Arduino IDE if you don't need the UF2 file.

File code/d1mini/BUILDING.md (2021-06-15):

# Building

1. Install Arduino IDE
2. Install ESP8266 Arduino core from git , NOT the usual Boards Manager way. [Instructions here](https://arduino-esp8266.readthedocs.io/en/latest/installing.html#using-git-version)
3. Install LittleFS arduino plugin [here](https://github.com/earlephilhower/arduino-esp8266littlefs-plugin) 
4. Upload sketch as normal.
5. Tools->ESP8266 LittleFS Data Upload

# ESP8266 Flash Layout

ESP8266 Flash Layout

### Creating BIN file

```shell
esptool --port COM9 --baud 921600 read_flash 0x00000 0x400000 d1mini.bin
```

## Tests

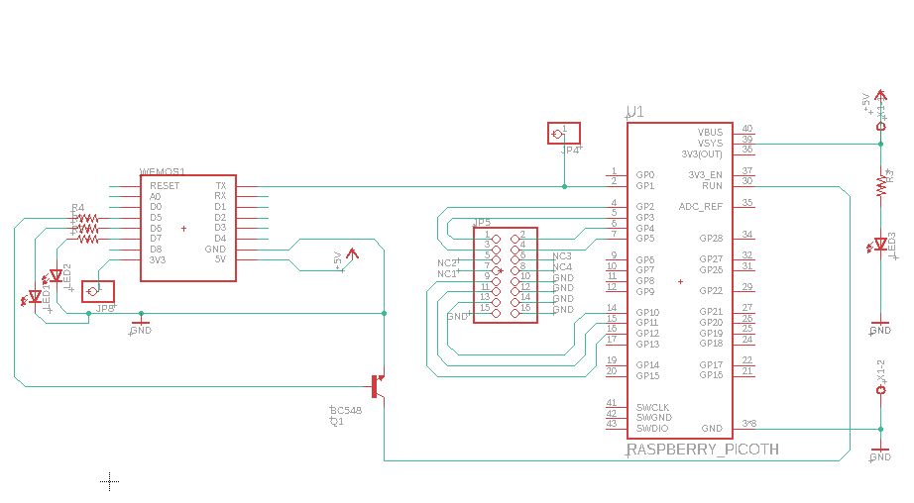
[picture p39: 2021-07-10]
eagle/Brians test board 16-schematic.png

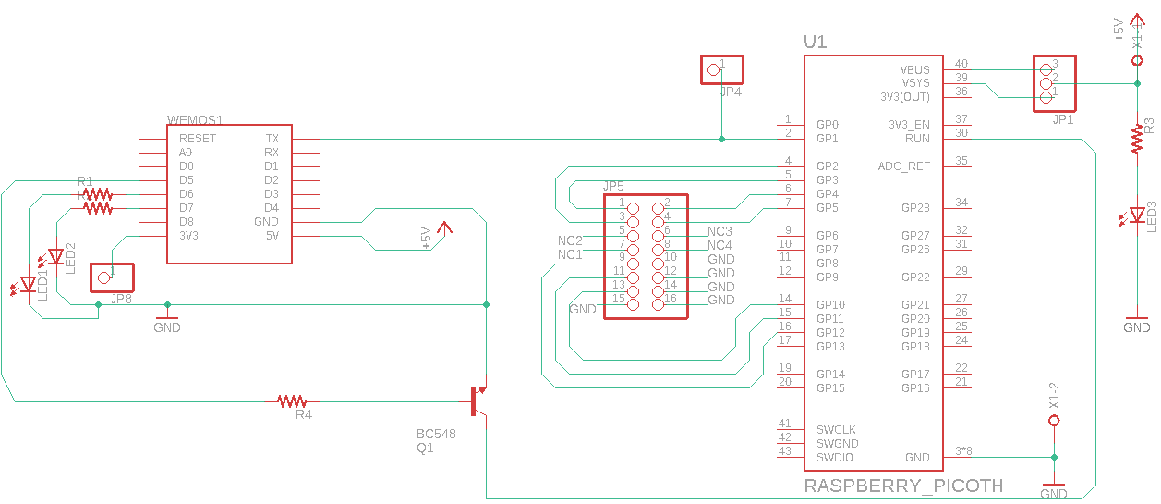
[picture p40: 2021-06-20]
eagle/Brians test board 1.12a-schematic-mohan.png

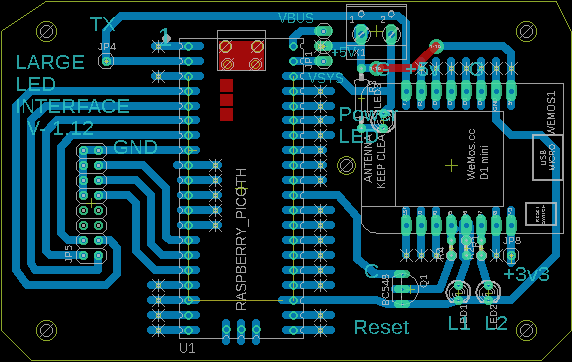
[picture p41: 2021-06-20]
eagle/Brians test board 1.12a-board-mohan.png

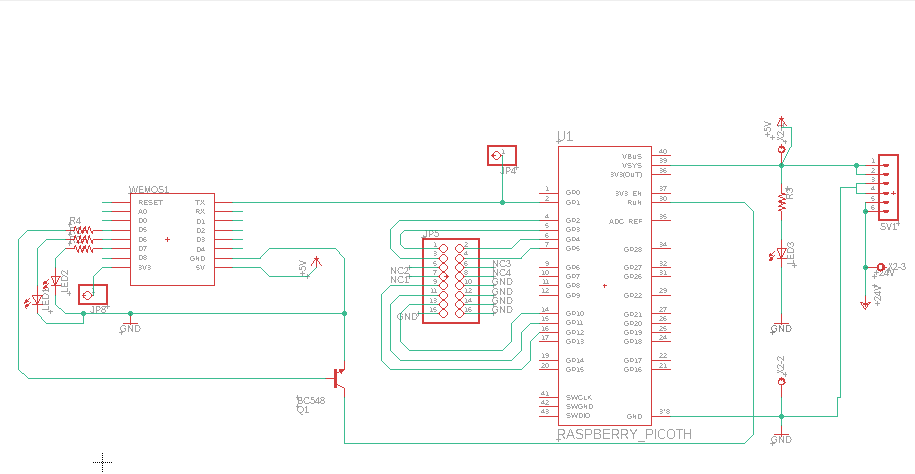
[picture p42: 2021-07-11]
eagle/Brians test board 17-schematic.png

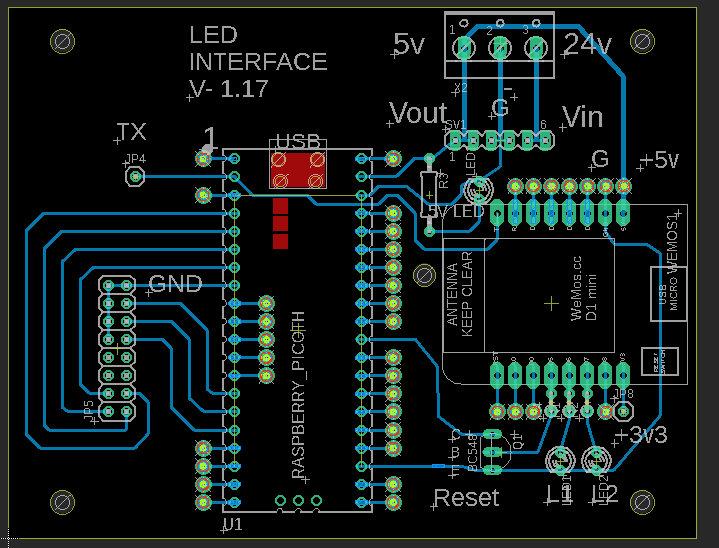
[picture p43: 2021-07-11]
eagle/Brians test board 17-board.png

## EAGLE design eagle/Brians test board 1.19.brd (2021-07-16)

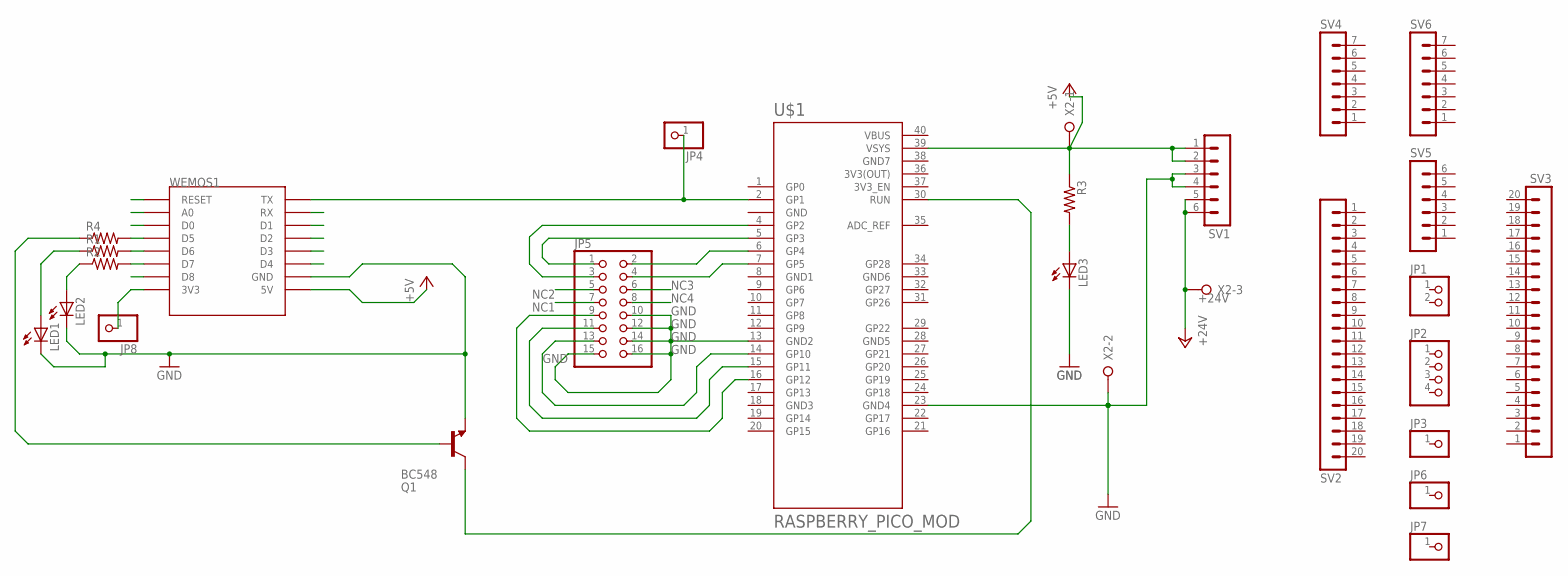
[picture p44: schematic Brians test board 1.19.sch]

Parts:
JP1: PINHD-1X2; 1X02
JP2: PINHD-1X4; 1X04
JP3, JP4, JP6, JP7, JP8: PINHD-1X1; 1X01
JP5: PINHD-2X8; 2X08
LED1, LED2, LED3: LED3MM
Q1: BC548; TO92-EBC
R1, R2, R4: R-US_0204/2V; 0204V
R3: R-US_0207/10; 0207/10
SV1, SV5: MA06-1
SV2, SV3: MA20-1
SV4, SV6: MA07-1
U$1: RASPBERRY_PICO_MOD; PICO-PKG-TH-LED
WEMOS1: WEMOS-D1-MINI
X2: W237-3E

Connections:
3V3(OUT): U$1.36 (3V3(OUT))
+5V: R3.1, SV1.1, SV1.2, U$1.39 (VSYS), WEMOS1.5V, X2.1
+24V: SV1.5, SV1.6, X2.3
A0: WEMOS1.A0
D0: WEMOS1.D0
D1: WEMOS1.D1
D2: WEMOS1.D2
D3: WEMOS1.D3
D4: WEMOS1.D4
D8: WEMOS1.D8
GND: JP5.10, JP5.12, JP5.14, JP5.15, JP5.16, LED1.K (C), LED2.K (C), LED3.K (C), Q1.E, SV1.3, SV1.4, U$1.3 (GND), U$1.13 (GND2), U$1.23 (GND4), WEMOS1.GND, X2.2
GND1: U$1.8 (GND1)
GND3: U$1.18 (GND3)
GND5: U$1.28 (GND5)
GND6: U$1.33 (GND6)
GND7: U$1.38 (GND7)
unnamed: JP5.1, U$1.5 (GP3)
unnamed: JP8.1, WEMOS1.3V3
unnamed: Q1.C, U$1.30 (RUN)
unnamed: JP4.1, U$1.2 (GP1), WEMOS1.TX
unnamed: JP5.3, U$1.4 (GP2)
unnamed: R2.2, WEMOS1.D7
unnamed: JP5.13, U$1.14 (GP10)
unnamed: JP5.11, U$1.15 (GP11)
unnamed: JP5.9, U$1.16 (GP12)
unnamed: JP5.2, U$1.6 (GP4)
unnamed: JP5.4, U$1.7 (GP5)
unnamed: R1.2, WEMOS1.D6
unnamed: LED2.A, R2.1
unnamed: LED1.A, R1.1
unnamed: LED3.A, R3.2
unnamed: R4.2, WEMOS1.D5
unnamed: Q1.B, R4.1
NC1: JP5.7
NC2: JP5.5
NC3: JP5.6
NC4: JP5.8
RST: WEMOS1.RESET
RX: WEMOS1.RX
VBUS: U$1.40 (VBUS)

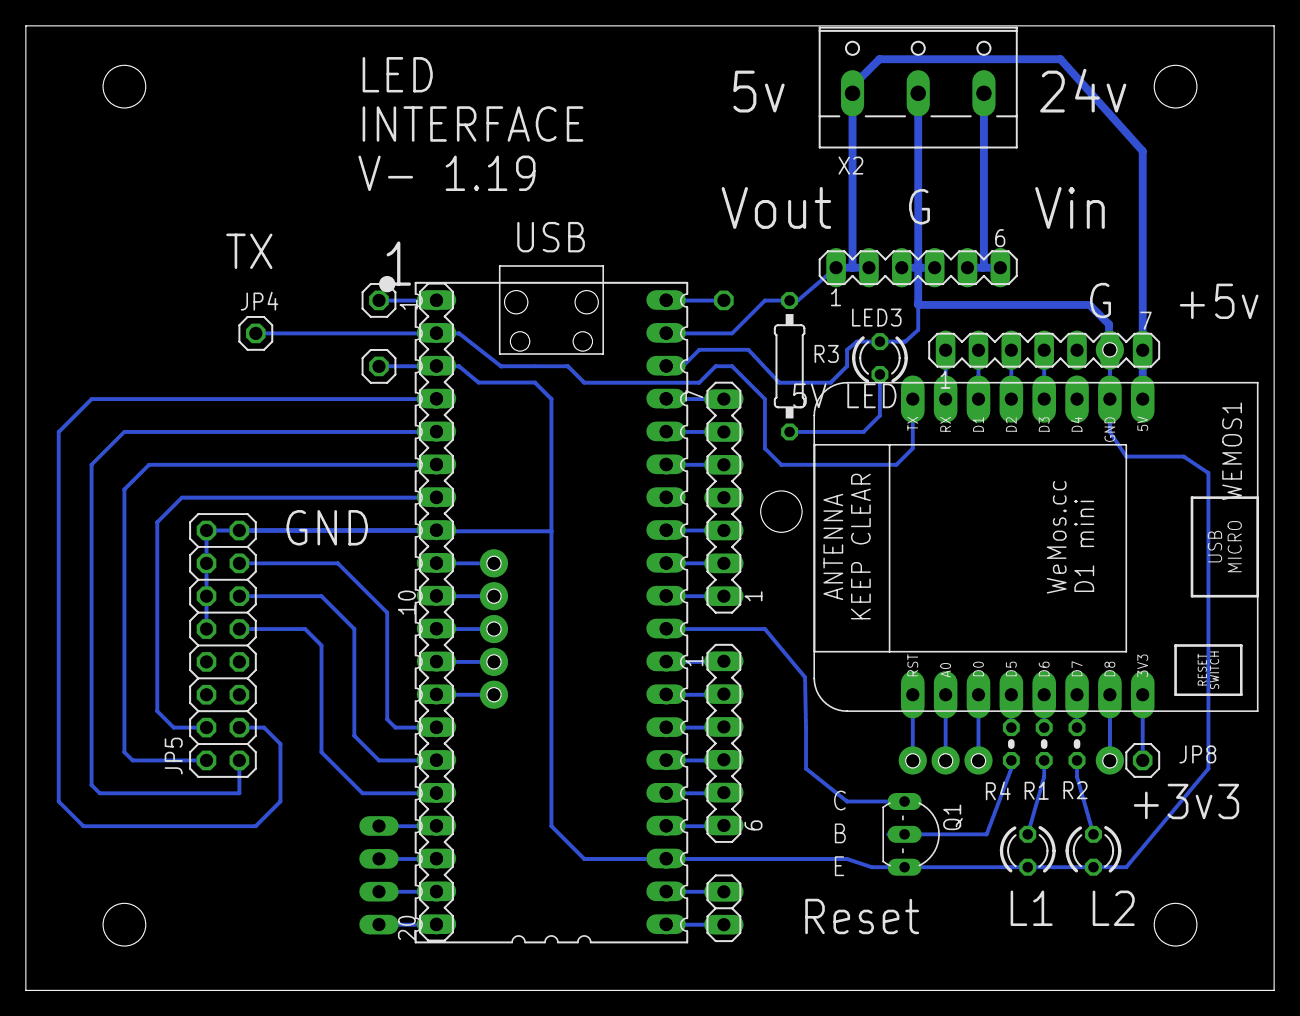
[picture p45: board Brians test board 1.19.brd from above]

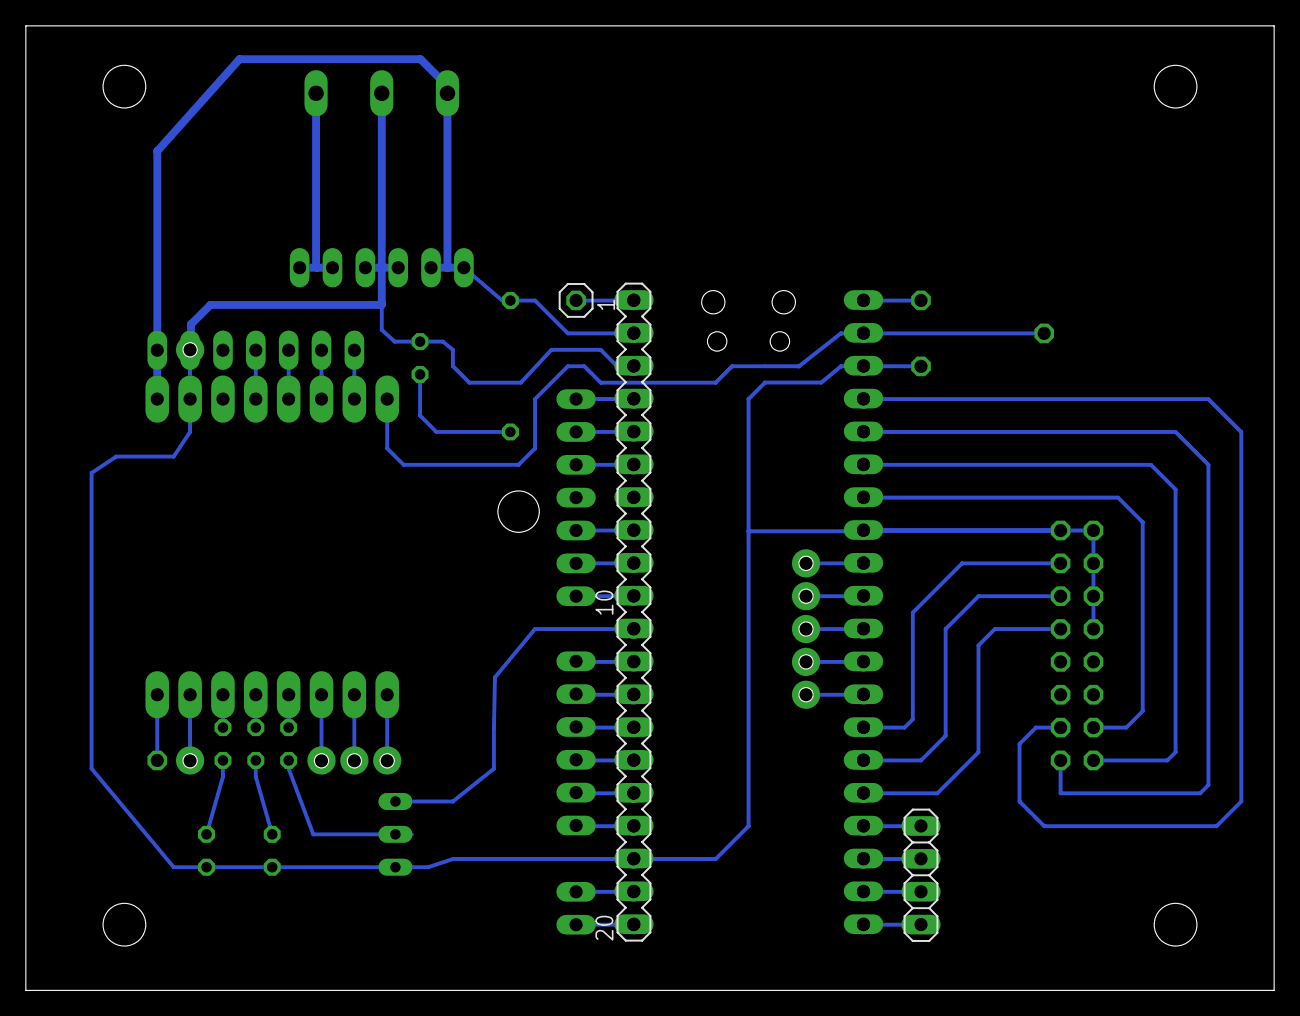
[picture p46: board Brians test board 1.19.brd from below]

Board: 2 copper layers, 96.5 x 74.6 mm, 25 parts (3 on the bottom side), 20 nets.

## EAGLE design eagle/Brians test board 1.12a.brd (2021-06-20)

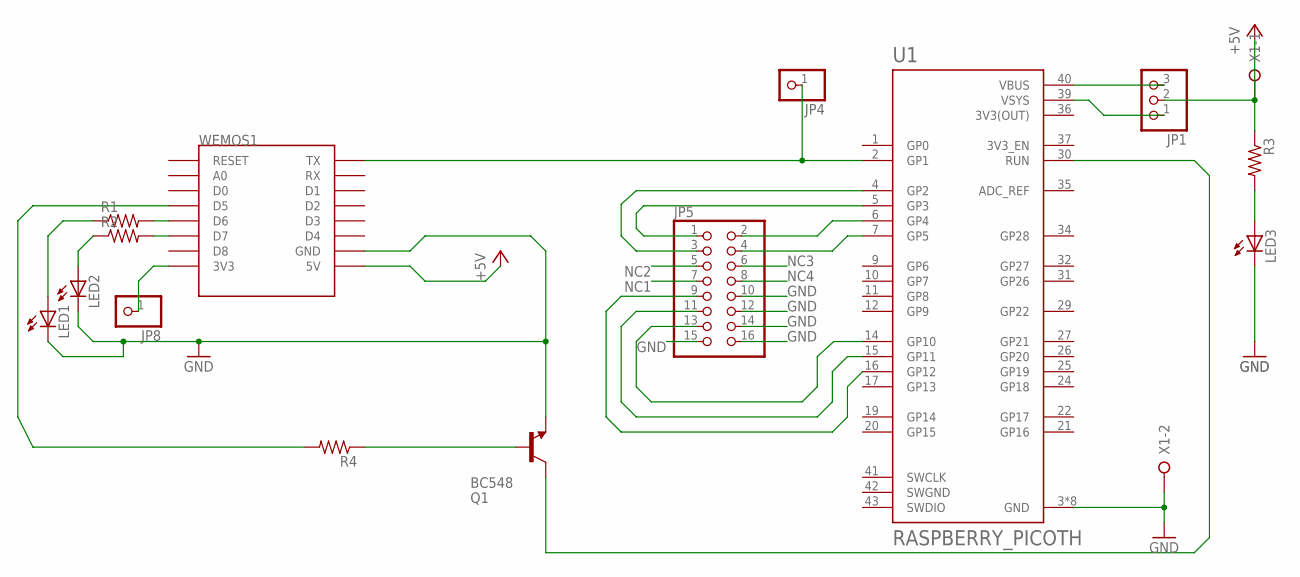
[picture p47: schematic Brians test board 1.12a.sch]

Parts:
JP1: PINHD-1X3; 1X03
JP4, JP8: PINHD-1X1; 1X01
JP5: PINHD-2X8; 2X08
LED1, LED2, LED3: LED3MM
Q1: BC548; TO92-EBC
R1, R2, R4: R-US_0204/2V; 0204V
R3: R-US_0207/10; 0207/10
U1: RASPBERRY_PICOTH; PICO-PKG-TH
WEMOS1: WEMOS-D1-MINI
X1: W237-02P; W237-132

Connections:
3V3(OUT): U1.36 (3V3(OUT))
+5V: JP1.2, R3.1, WEMOS1.5V, X1.1
GND: JP5.10, JP5.12, JP5.14, JP5.15, JP5.16, LED1.K (C), LED2.K (C), LED3.K (C), Q1.E, U1.3 (GND), U1.8 (GND), U1.13 (GND), U1.18 (GND), U1.23 (GND), U1.28 (GND), U1.33 (GND), U1.38 (GND), WEMOS1.GND, X1.2
unnamed: JP5.1, U1.5 (GP3)
unnamed: JP8.1, WEMOS1.3V3
unnamed: JP1.3, U1.40 (VBUS)
unnamed: Q1.C, U1.30 (RUN)
unnamed: JP4.1, U1.2 (GP1), WEMOS1.TX
unnamed: JP5.3, U1.4 (GP2)
unnamed: R2.2, WEMOS1.D7
unnamed: JP5.13, U1.14 (GP10)
unnamed: JP5.11, U1.15 (GP11)
unnamed: JP5.9, U1.16 (GP12)
unnamed: JP5.2, U1.6 (GP4)
unnamed: JP5.4, U1.7 (GP5)
unnamed: R1.2, WEMOS1.D6
unnamed: JP1.1, U1.39 (VSYS)
unnamed: LED2.A, R2.1
unnamed: LED1.A, R1.1
unnamed: LED3.A, R3.2
unnamed: R4.2, WEMOS1.D5
unnamed: Q1.B, R4.1
NC1: JP5.7
NC2: JP5.5
NC3: JP5.6
NC4: JP5.8
SWGND: U1.42 (SWGND)

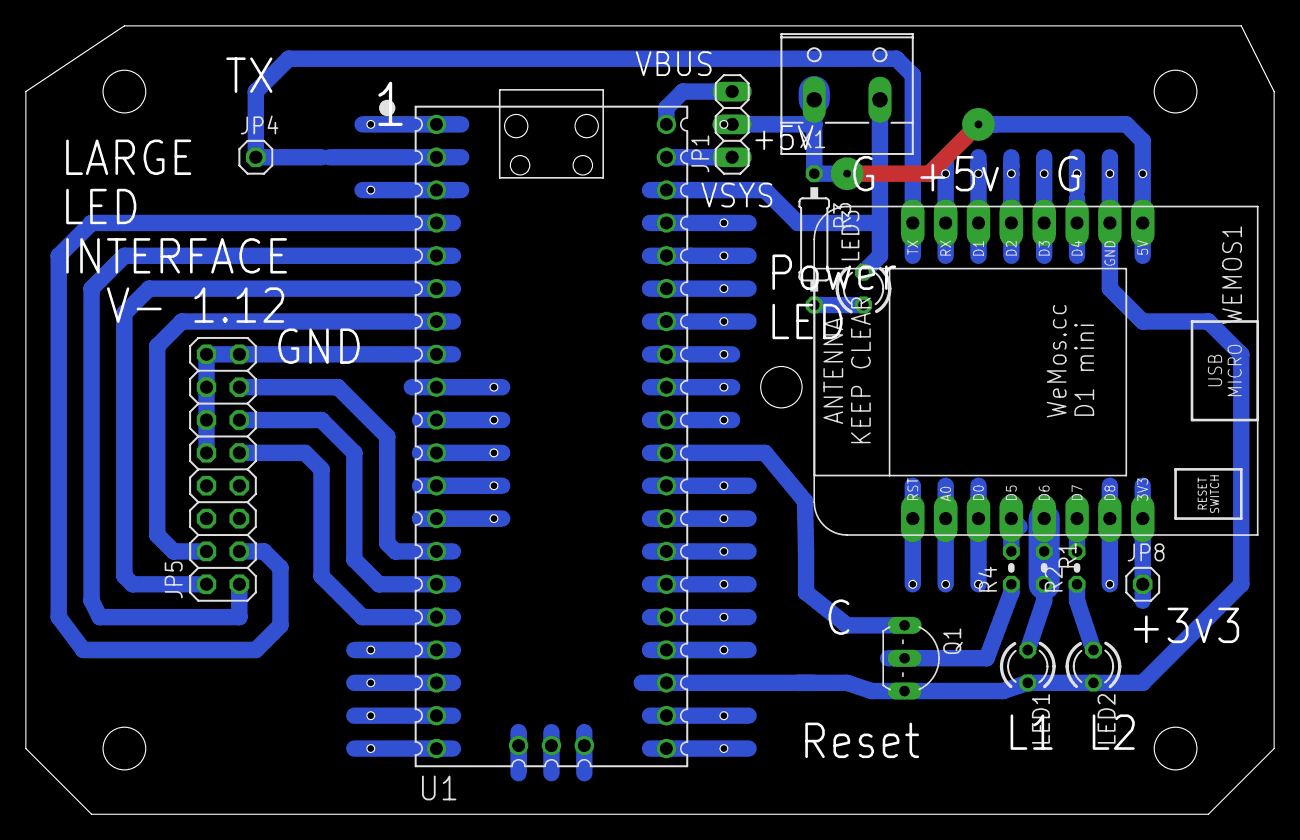
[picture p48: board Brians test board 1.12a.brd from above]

Board: 2 copper layers, 96.5 x 61.0 mm, 15 parts (0 on the bottom side), 21 nets.

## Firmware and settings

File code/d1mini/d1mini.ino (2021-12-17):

#include <DNSServer.h>
#ifdef ESP32
#include <WiFi.h>
#include <AsyncTCP.h>
#elif defined(ESP8266)
//#include <ESP8266WiFi.h>
#include <ESP8266WiFiMulti.h>
#include <ESPAsyncTCP.h>
//#include <ESP8266mDNS.h>
#endif
#include "ESPAsyncWebServer.h"
#include <LittleFS.h>
#include <Ticker.h>
#include <AsyncJson.h>
#include <ArduinoJson.h>
#define WIFI_TIMEOUT 15000


//#define DEBUG 0
#define DEBUG 1

#define debug_print(val) do { if (DEBUG) Serial.print(val); } while(0)
#define debug_println(val) do { if (DEBUG) Serial.println(val); } while(0)
#define update_ledmatrix_ipaddress(val) do { Serial.print("{I`"); Serial.print(val);Serial.println("}"); } while(0)
#define update_ledmatrix_command(val) do { Serial.print("{"); Serial.print(val);Serial.println("}"); } while(0)
#define update_ledmatrix_command_with_arg(command, arg1) do {Serial.print("{"); Serial.print(command);Serial.print("`");Serial.print(arg1);Serial.println("}"); } while(0)
#define update_ledmatrix_command_with_two_args(command, arg1, arg2) do {Serial.print("{"); Serial.print(command);Serial.print("`");Serial.print(arg1);Serial.print("`");Serial.print(arg2);Serial.println("}"); } while(0)

DNSServer dnsServer;
AsyncWebServer server(80);
bool restartESP = false;
Ticker ticker;
ESP8266WiFiMulti wifiMulti;

void restartESPCallback()
{
  ESP.restart();
}

class CaptiveRequestHandler : public AsyncWebHandler {
  public:
    CaptiveRequestHandler() {

      server.serveStatic("/css/", LittleFS, "/css/");
      server.serveStatic("/js/", LittleFS, "/js/");
      server.serveStatic("/fonts/", LittleFS, "/fonts/");
      server.serveStatic("/favicon.ico", LittleFS, "/favicon.ico");
      server.serveStatic("/games/", LittleFS, "/games/").setDefaultFile("index.html");

      server.on("/wificredentials", HTTP_POST, [](AsyncWebServerRequest * request) {
        int params = request->params();
        AsyncWebParameter *ssid = request->getParam(0);
        AsyncWebParameter *wifipassword = request->getParam(1);
        AsyncWebParameter *ssid2 = request->getParam(2);
        AsyncWebParameter *wifipassword2 = request->getParam(3);

        debug_print("Number of params: ");
        debug_println(params);
        debug_print("SSID: ");
        debug_println(ssid->value().c_str());
        debug_print("Wifi password: ");
        debug_println(wifipassword->value().c_str());
        debug_print("SSID2: ");
        debug_println(ssid2->value().c_str());
        debug_print("Wifi password2: ");
        debug_println(wifipassword2->value().c_str());

        File file = LittleFS.open("wifi.cfg", "w");
        file.print(ssid->value().c_str());
        file.print('\n');
        file.print(wifipassword->value().c_str());
        file.print('\n');
        file.print(ssid2->value().c_str());
        file.print('\n');
        file.print(wifipassword2->value().c_str());
        file.print('\n');
        file.close();
        /*
          file.print(ssid->value().c_str());
          file.print(',');
          file.print(wifipassword->value().c_str());
          file.close();
        */

        AsyncWebServerResponse* response = request->beginResponse(LittleFS, "/captiverestart.htm", "text/html");
        request->send(response);
        ticker.attach(5, restartESPCallback);
      });

      server.on("/main", HTTP_GET, [](AsyncWebServerRequest * request) {
        request->send(LittleFS,  "/index.htm", "text/html");
      });

      server.on("/command", HTTP_POST, [](AsyncWebServerRequest * request) {
        int params = request->params();
        AsyncWebParameter *c = request->getParam(0);
        char command[100];
        strcpy(command,  c->value().c_str());

        debug_print("{");
        debug_print(*command);

        for (int i = 1; i < params; i++) {
          debug_print("`");

          AsyncWebParameter *d = request->getParam(i);
          debug_print(d->value().c_str());
        }

        debug_print("}");
        debug_println();


        request->send(204);
      });

      server.on("/newpanelsize", HTTP_POST, [](AsyncWebServerRequest * request) {
        int params = request->params();
        AsyncWebParameter *c = request->getParam(0);
        AsyncWebParameter *d = request->getParam(1);
        char width[10];
        char height[10];
        strcpy(width,  c->value().c_str() );
        strcpy(height, d->value().c_str() );
  
        File settingsFile = LittleFS.open("/settings.json", "r");
        DynamicJsonDocument doc(1024);
        deserializeJson(doc, settingsFile);
        JsonObject root = doc.as<JsonObject>();
        settingsFile.close();
        File settings2File = LittleFS.open("/settings.json", "w");
        root["panelwidth"] = String(width);
        root["panelheight"] = String(height);
        serializeJson(doc, settings2File);
        settings2File.close();
        
        update_ledmatrix_command_with_two_args("~", width, height);
        
        request->send(204);
      });

      server.on("/settings", HTTP_GET, [](AsyncWebServerRequest * request) {
        File settingsFile = LittleFS.open("/settings.json", "r");
        request->send(200, "application/json", settingsFile.readString());
        settingsFile.close();
      });

    }
    virtual ~CaptiveRequestHandler() {}

    bool canHandle(AsyncWebServerRequest *request) {
      //request->addInterestingHeader("ANY");
      return true;
    }

    void handleRequest(AsyncWebServerRequest *request) {
      //AsyncResponseStream *response = request->beginResponseStream("text/html");
      request->send(LittleFS,  "/captiveportal.htm", "text/html");
      // Captive portal is at: 192.168.4.1
      //request->send(response);
    }
};




void startCaptiveWebServer()
{
  WiFi.disconnect();
  delay(50);
  WiFi.mode(WIFI_AP); // Access Point mode
  delay(50);
  WiFi.softAP("brianLEDPanels");
  dnsServer.start(53, "*", WiFi.softAPIP());
  server.addHandler(new CaptiveRequestHandler()).setFilter(ON_AP_FILTER);//only when requested from AP
  server.begin();
  // brightness
  update_ledmatrix_command_with_arg('B', "1");
  update_ledmatrix_ipaddress("192.168.4.1");
}

void startWebServer()
{
  server.serveStatic("/css/", LittleFS, "/css/");
  server.serveStatic("/js/", LittleFS, "/js/");
  server.serveStatic("/fonts/", LittleFS, "/fonts/");
  server.serveStatic("/favicon.ico", LittleFS, "/favicon.ico");
  server.serveStatic("/games/", LittleFS, "/games/").setDefaultFile("index.html");

  server.on("/command", HTTP_POST, [](AsyncWebServerRequest * request) {
    int params = request->params();
    AsyncWebParameter *c = request->getParam(0);
    char command[100];
    strcpy(command,  c->value().c_str());

    debug_print("{");
    debug_print(*command);

    for (int i = 1; i < params; i++) {
      debug_print("`");

      AsyncWebParameter *d = request->getParam(i);
      debug_print(d->value().c_str());
    }

    debug_print("}");
    debug_println();


    request->send(204);
  });

  AsyncCallbackJsonWebHandler* handler = new AsyncCallbackJsonWebHandler("/homeassistant", [](AsyncWebServerRequest * request, JsonVariant & json) {
    { //scope JsonDocument so it releases its buffer
      JsonObject jsonObj = json.as<JsonObject>();
      const char *command = jsonObj["command"];
      int argumentCount = jsonObj["argumentCount"];

      Serial.print("{");
      Serial.print(command);
      for (int i = 0; i < argumentCount; i++) {
        const char *argument = jsonObj["arguments"][i];
        Serial.print("`");
        Serial.print(argument);
      }
      Serial.print("}");
      Serial.println();
      request->send(200);
    }
  });
  server.addHandler(handler);

  AsyncCallbackJsonWebHandler* settingsSubmitHandler = new AsyncCallbackJsonWebHandler("/settingsSubmit", [](AsyncWebServerRequest * request, JsonVariant & json) {


    if (request->method() == HTTP_POST) {
      DynamicJsonDocument doc(2048);
      doc["brightness"] = json["brightness"];
      doc["bootcommand"] = json["bootcommand"];
      doc["bootcommanddescription"] = json["bootcommanddescription"];
      doc["panelwidth"] = json["panelwidth"];
      doc["panelheight"] = json["panelheight"];

      String brightness = json["brightness"];
      update_ledmatrix_command_with_arg('B', brightness);

      File settingsFile = LittleFS.open("/settings.json", "w");
      serializeJson(json, settingsFile);
      request->send(200);
      settingsFile.close();
    }



  });

  server.addHandler(settingsSubmitHandler);

  server.on("/settings", HTTP_GET, [](AsyncWebServerRequest * request) {
    File settingsFile = LittleFS.open("/settings.json", "r");
    request->send(200, "application/json", settingsFile.readString());
    settingsFile.close();
  });

  server.on("/savedsettings", HTTP_GET, [](AsyncWebServerRequest * request) {
    File settingsFile = LittleFS.open("/settings.json", "r");
    request->send(settingsFile, "application/json", settingsFile.size());
    settingsFile.close();
  });

  server.on("/wifisettings", HTTP_GET, [](AsyncWebServerRequest * request) {
    File wifiFile = LittleFS.open("/wifi.cfg", "r");
    String ssid1 = wifiFile.readStringUntil('\n');
    String password1 = wifiFile.readStringUntil('\n');
    String ssid2 = wifiFile.readStringUntil('\n');
    String password2 = wifiFile.readStringUntil('\n');
    wifiFile.close();

    AsyncJsonResponse * response = new AsyncJsonResponse();
    JsonVariant& root = response->getRoot();
    root["ssid1"] = ssid1.c_str();
    root["password1"] = password1.c_str();
    root["ssid2"] = ssid2.c_str();
    root["password2"] = password2.c_str();
    response->setLength();
    request->send(response);
  });

  server.on("/wifisettings", HTTP_POST, [](AsyncWebServerRequest * request) {
    AsyncWebParameter *ssid1 = request->getParam(0);
    AsyncWebParameter *password1 = request->getParam(1);
    AsyncWebParameter *ssid2 = request->getParam(2);
    AsyncWebParameter *password2 = request->getParam(3);

    File settingsFile = LittleFS.open("/wifi.cfg", "w");

    settingsFile.print(ssid1->value().c_str());
    settingsFile.print('\n');
    settingsFile.print(password1->value().c_str());
    settingsFile.print('\n');
    settingsFile.print(ssid2->value().c_str());
    settingsFile.print('\n');
    settingsFile.print(password2->value().c_str());
    settingsFile.print('\n');

    settingsFile.close();
    request->send(204);
  });

  server.on("/", HTTP_GET, [](AsyncWebServerRequest * request) {
    request->send(LittleFS,  "/index.htm", "text/html");
  });




  server.begin();

  debug_println("Web server started");


}

bool attemptWifiConnection()
{
  File f = LittleFS.open("wifi.cfg", "r");

  if (f.available() > 0) {
    String ssid = f.readStringUntil('\n');
    String password = f.readStringUntil('\n');
    String ssid2 = f.readStringUntil('\n');
    String password2 = f.readStringUntil('\n');
    wifiMulti.addAP(ssid.c_str(), password.c_str());
    wifiMulti.addAP(ssid2.c_str(), password2.c_str());
    if (wifiMulti.run(WIFI_TIMEOUT) == WL_CONNECTED) {
      Serial.print("WiFi connected: ");
      Serial.print(WiFi.SSID());
      Serial.print(" ");
      Serial.println(WiFi.localIP());
      f.close();
      return true;
    } else {
      Serial.println("WiFi not connected!");
      f.close();
      return false;
    }
  }

  return false;

}

void send_bootcommand(const String& ipaddress) {
  File settingsFile = LittleFS.open("/settings.json", "r");
  DynamicJsonDocument doc(1024);
  deserializeJson(doc, settingsFile);
  JsonObject root = doc.as<JsonObject>();
  String bootcommand = root["bootcommand"];
  String brightness = root["brightness"];
  update_ledmatrix_command_with_arg("B", brightness);
  if (bootcommand == "") {
    debug_print("IP Address: ");
    debug_println(ipaddress);
    update_ledmatrix_ipaddress(ipaddress);
  }

  else {
    update_ledmatrix_command(bootcommand);
  }

  settingsFile.close();
}

void wificonfig()
{
  bool successfulWifiConnection = attemptWifiConnection();

  if (successfulWifiConnection) {
    debug_println("Successfully connected to wifi.");
    send_bootcommand(WiFi.localIP().toString());
    startWebServer();
  }

  else {
    debug_println("Starting captive portal...");
    debug_println("Creating WIFI network: brianLEDPanels");
    debug_println("IP address: 192.168.4.1");
    startCaptiveWebServer();
  }

}

void setup() {
  Serial.begin(115200);
  delay(5000);
  if (DEBUG)
    Serial.println("Debugging ON.");
  else
    Serial.println("Debugging OFF.");
  debug_println("begin wifi route...");

  if (!LittleFS.begin()) {
    delay(5000);
    debug_println("An Error has occurred while mounting LittleFS. Did you forget to upload fs using ESP8266 LittleFS Data upload?");
    return;
  }

  if (!LittleFS.exists("wifi.cfg"))
  {
    delay(5000);
    debug_println("wifi.cfg does not exist. Did you forget to upload fs using ESP8266 LittleFS Data upload?");
    return;
  }

  WiFi.persistent(false);
  WiFi.mode(WIFI_STA);

  wificonfig();
}

void loop() {
  if (restartESP) {
    restartESP = false;
    ESP.restart();
  }
  dnsServer.processNextRequest();
}

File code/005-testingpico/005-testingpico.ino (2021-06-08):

#include "MBI5039.h"

#define PIN_DATA1 3 
#define PIN_DATA2 4
#define PIN_DATA3 5
#define PIN_DATA4 2

#define PIN_CLK 12
#define PIN_LATCH 11 
#define PIN_NOE 10

#define DATA_SEGMENTS_PER_PANEL 4

MBI5039 mbi(PIN_CLK, PIN_LATCH, PIN_NOE, PIN_DATA1, PIN_DATA2, PIN_DATA3, PIN_DATA4);

void latchAndEnable()
{
  digitalWrite(PIN_NOE, HIGH);
  digitalWrite(PIN_LATCH, HIGH);
  delayMicroseconds(250);
  digitalWrite(PIN_LATCH, LOW);
  delayMicroseconds(250);
  digitalWrite(PIN_NOE, LOW);
  analogWrite(PIN_NOE, 900);
}

//This lights up top left hand corner
void test1() 
{
  //mbi.sendData(data4,data2, )
  mbi.sendData(0b00000000, 0b00000000, 0b00000000, 0b00000000, true);
  mbi.sendData(0b00000000, 0b00000000, 0b00000000, 0b00000000, true);
  mbi.sendData(0b00000000, 0b00000000, 0b00000000, 0b00000000, true);
  mbi.sendData(0b00000000, 0b00000000, 0b00000000, 0b00000000, true);
  mbi.sendData(0b00000000, 0b00000000, 0b00000000, 0b00000000, true);
  mbi.sendData(0b00000000, 0b00000000, 0b00000000, 0b00000000, true);
  mbi.sendData(0b00000000, 0b00000000, 0b00000000, 0b00000000, true);
  mbi.sendData(0b00000000, 0b00000001, 0b00000000, 0b00000000, true);
  //mbi.sendData(0b0000000000000000, 0b0000000000000000, 0b0000000000000000, 0b0000000000000000, true);
  //mbi.sendData(0b0000000000000000, 0b0000000000000000, 0b0000000000000000, 0b0000000000000000, true);
  //mbi.sendData(0b0000000000000000, 0b0000000000000000, 0b0000000000000000, 0b0000000000000000, true);
  //mbi.sendData(0b0000000000000000, 0b0000000000000001, 0b0000000000000000, 0b0000000000000000, true);
}

//This lights up bottom right hand corner
void test2() 
{
  //mbi.sendData(data4,data2, )
  mbi.sendData(0b00000000, 0b00000000, 0b00000001, 0b00000000, true);
  mbi.sendData(0b00000000, 0b00000000, 0b00000000, 0b00000000, true);
  mbi.sendData(0b00000000, 0b00000000, 0b00000000, 0b00000000, true);
  mbi.sendData(0b00000000, 0b00000000, 0b00000000, 0b00000000, true);
  mbi.sendData(0b00000000, 0b00000000, 0b00000000, 0b00000000, true);
  mbi.sendData(0b00000000, 0b00000000, 0b00000000, 0b00000000, true);
  mbi.sendData(0b00000000, 0b00000000, 0b00000000, 0b00000000, true);
  mbi.sendData(0b00000000, 0b00000000, 0b00000000, 0b00000000, true);
  //mbi.sendData(0b0000000000000000, 0b0000000000000000, 0b0000000100000000, 0b0000000000000000, true);
  //mbi.sendData(0b0000000000000000, 0b0000000000000000, 0b0000000000000000, 0b0000000000000000, true);
  //mbi.sendData(0b0000000000000000, 0b0000000000000000, 0b0000000000000000, 0b0000000000000000, true);
  //mbi.sendData(0b0000000000000000, 0b0000000000000000, 0b0000000000000000, 0b0000000000000000, true);
}

//This lights up Top right h0and corner
void test3() 
{
  
  //mbi.sendData(data4,data2, )0
  mbi.sendData(0b00000000, 0b00000000, 0b00000000, 0b00000000, true);
  mbi.sendData(0b00000000, 0b00000000, 0b00000000, 0b00000000, true);
  mbi.sendData(0b00000000, 0b00000000, 0b00000000, 0b00000000, true);
  mbi.sendData(0b00000000, 0b00000000, 0b00000000, 0b00000000, true);
  mbi.sendData(0b00000000, 0b00000000, 0b00000000, 0b00000000, true);
  mbi.sendData(0b00000000, 0b00000000, 0b00000000, 0b00000000, true);
  mbi.sendData(0b00000000, 0b00000000, 0b00000000, 0b00000001, true);
  mbi.sendData(0b00000000, 0b00000000, 0b00000000, 0b00000000, true);
  //mbi.sendData(0b0000000000000000, 0b0000000000000000, 0b0000000000000000, 0b0000000000000000, false);
  //mbi.sendData(0b0000000000000000, 0b0000000000000000, 0b0000000000000000, 0b0000000000000000, false);
  //mbi.sendData(0b0000000000000000, 0b0000000000000000, 0b0000000000000000, 0b0000000000000000, false);
  //mbi.sendData(0b0000000000000000, 0b0000000000000000, 0b0000000000000000, 0b0000000010000000, false);
}

//This lights up bottom left hand corner
void test4() 
{
  //mbi.sendData(data4,data2,data1,data3)
  mbi.sendData(0b10000000, 0b00000000, 0b00000000, 0b00000000, true);
  mbi.sendData(0b00000000, 0b00000000, 0b00000000, 0b00000000, true);
  mbi.sendData(0b00000000, 0b00000000, 0b00000000, 0b00000000, true);
  mbi.sendData(0b00000000, 0b00000000, 0b00000000, 0b00000000, true);
  mbi.sendData(0b00000000, 0b00000000, 0b00000000, 0b00000000, true);
  mbi.sendData(0b00000000, 0b00000000, 0b00000000, 0b00000000, true);
  mbi.sendData(0b00000000, 0b00000000, 0b00000000, 0b00000000, true);
  mbi.sendData(0b00000000, 0b00000000, 0b00000000, 0b00000000, true);
  //mbi.sendData(0b1000000000000000, 0b0000000000000000, 0b0000000000000000, 0b0000000000000000, false);
  //mbi.sendData(0b0000000000000000, 0b0000000000000000, 0b0000000000000000, 0b0000000000000000, false);
  //mbi.sendData(0b0000000000000000, 0b0000000000000000, 0b0000000000000000, 0b0000000000000000, false);
  //mbi.sendData(0b0000000000000000, 0b0000000000000000, 0b0000000000000000, 0b0000000000000000, false);
}


void setup() {
  Serial.begin(115200);
  
  pinMode(PIN_CLK, OUTPUT);
  pinMode(PIN_LATCH, OUTPUT);
  pinMode(PIN_NOE, OUTPUT);
  pinMode(PIN_DATA1, OUTPUT);
  pinMode(PIN_DATA2, OUTPUT);
  pinMode(PIN_DATA3, OUTPUT);
  pinMode(PIN_DATA4, OUTPUT);

  delay(2000);
  
  digitalWrite(PIN_NOE, HIGH);
  digitalWrite(PIN_CLK, LOW);
  digitalWrite(PIN_LATCH, LOW);
  digitalWrite(PIN_DATA1, LOW);
  digitalWrite(PIN_DATA2, LOW);
  digitalWrite(PIN_DATA3, LOW);
  digitalWrite(PIN_DATA4, LOW);

  delay(1000);

  //0b0000000000000000
  //0b1111111111111111
  //0b1010101010101010
  //0b1110000000000101
  //0b0000000000000100
  //0b0000001100000000

  // Bad news: 1 is on ON, 0 is OFF

  //data4: u18-u21 
  //data3: u14-u17
  //data2: u10-u13
  //data1: u6-u9

  /*
  uint16_t data1 = 0b0111111111111111;
  uint16_t data2 = 0b1111111111111111;
  uint16_t data3 = 0b1111111111111111;
  uint16_t data4 = 0b1111111111111111;
*/
  //test1();
  //test2();
  //test3();
  test4();
  /*
  for (int i=0; i<8; i++)
  {
    digitalWrite(PIN_DATA2, HIGH);
    delayMicroseconds(10);
    digitalWrite(PIN_DATA2, LOW);
    delayMicroseconds(10);
  }

  delay(1);
  for (int i=0; i<8; i++)
  {
    digitalWrite(PIN_DATA4, HIGH);
    delayMicroseconds(10);
    digitalWrite(PIN_DATA4, LOW);
    delayMicroseconds(10);
  }
  */
  
  /*
  for (int i=0; i<DATA_SEGMENTS_PER_PANEL; i++)
  {
    mbi.sendData(data1, data2, data3, data4, false);
    delayMicroseconds(250);
  }
*/
  /*
    mbi.sendData(0b1111111111111111, 0b1111111111111111, 0b1111111111111111, 0b1111111100000000, false);
    mbi.sendData(0b1111111111111111, 0b1111111111111111, 0b1111111111111111, 0b1111111111111111, false);
    mbi.sendData(0b1111111111111111, 0b1111111111111111, 0b1111111111111111, 0b1111111111111111, false);
    mbi.sendData(0b1111111111111111, 0b1111111111111111, 0b1111111111111111, 0b1111111111111111, false);   
   */
/*
  digitalWrite(PIN_LATCH, HIGH);
  delayMicroseconds(250);
  digitalWrite(PIN_LATCH, LOW);
  delayMicroseconds(250);
  digitalWrite(PIN_NOE, LOW);
  analogWrite(PIN_NOE, 900);
  */
  //delay(5000);
  //digitalWrite(PIN_NOE, HIGH);
}

//int brightnessLevel = 1023;
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

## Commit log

2021-05-23 Changed to non-inverting display
    [DMDv3.h, MBI5039.cpp]
2021-06-12 pico works, pins correct
2021-06-13 cleanup code directory
    [wifi.cfg]
2021-06-13 added new code directory
    [wifi.cfg]
2021-06-30 Create script.LED Update
2021-06-30 Create script.LED Panel
2021-06-30 Rename script.LED Panel to script.LED Panel.yaml
2021-06-30 Rename script.LED Update to script.LED Update.yaml
2021-12-07 Major bug if panel size width > 6 investigating
    [demo-multipanel.ino]
2021-12-08 add reset command to pico
2021-12-08 panel size sent to pico
2021-12-11 pico panel size stroage now stable
2021-12-11 changed screenshot of PCB on front page
2021-12-11 add riplple effect to button
2021-12-12 pico: added one line scroll
